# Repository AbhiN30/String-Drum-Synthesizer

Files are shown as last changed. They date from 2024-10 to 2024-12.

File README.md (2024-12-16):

# String/Drum Synthesizer (Initial Project Proposal)

## Team Members:
- Abhi Nayak (arnayak2) 
- Joel Schurgin (joelbs3)

## Problem
A musical artist brings with them a sense of how to evoke certain emotions or create particular atmospheres, but may lack the technical knowledge to bring it to life. Sound design can be challenging as it involves crafting the unique timbres and textures that define a piece of music, which can be both an art and a science. The learning curve is steep, not only because it requires a grasp of complex technical tools but also because it demands a creative intuition that isn't easily taught. Musicians and producers must learn to navigate a vast array of software and hardware tools, each with its own set of knobs, sliders, and buttons. Understanding how to shape sounds means diving deep into the physics of sound waves, the principles of digital signal processing, and the subtleties of different synthesis methods. This process can feel overwhelming, especially for beginners who might feel lost amidst the jargon and the sheer number of options.

## Solution
Our proposal is to build a synthesizer. A synthesizer is a machine that is capable of producing a range of sounds when given a simple key or noise pulse. The range of sounds are controlled by a set of parameters such as filter cutoffs, oscillator types, low frequency oscillators, etc. The proposed solution is two-fold. The first part of the project is to build emotive knobs that feature descriptive ranges such as soft to aggressive or thin to thick. These knobs would also control the internal parameters of the system to achieve the desired effects on the input sound. The other part is to create a system that records a sound and finds the best way to set the synthesizer's internal parameters to recreate it. The intended work flow of this device for a musical artist is to record a sound, tweak the knobs, and play that sound by pressing a key on a MIDI keyboard. It is up to the musician to record the sound into their own recording software for further manipulation.

# Solution Components
## Subsystem 1: Power Block

Purpose/Requirements: This subsystem must be able to power the processor and the USB keyboard. Capacitors will be used to stabilize the power block.

Components:

- 5V DC Power Supply Adapter
- Capacitors
- Subsystem 2: Synthesizer

## Subsystem 2: Software Synthesizer
Purpose/Requirements: This subsystem will generate sounds using the Karplus Strong algorithm which features a pulse generator and an echo chamber (modeled with digital delay, feedback, and filtering). When a note is played on a USB keyboard, this component must be able to change the pitch based on which key is pressed. The algorithm’s parameters must be controllable using potentiometers, but several parameters can be determined as a function of one knob. We chose the Karplus Strong algorithm to reduce the computational load, but we are modifying certain aspects to allow for a greater range of sounds. The pulse that we will use is a blend of noise and sine wave oscillator which are added together and distorted. In addition, there will be some soft distortion applied on the output. In addition, the echo chamber will use 3 IIR filters: highpass, lowpass, and a bell. The choice to use IIR filters is to lower the amount of computation.

We made a demo of the synthesizer algorithm using a digital audio workstation in order to play with parameters and determine the names of the emotive knobs. Below are the emotive knobs and how the corresponding synth parameters should change to implement them:

Aggression

- Synth Params: Pulse distortion, output distortion
- Knob Left: Low distortion
- Knob Right: High distortion

Brightness

- Synth Param: Low pass filter cutoff
- Knob Left: 20 Hz
- Knob Right: 20 kHz

Boominess

- Synth Param: High pass Cutoff
- Knob Left: 20 kHz
- Knob Center: Note pitch
- Knob Right: 20 Hz

Dampening

- Synth Param: Bell Q
- Knob Left: High Q
- Knob Right: Low Q

*Not sure what to call this yet, but it affects how the echo chamber resonates. Note: setting this to around 3.6 kHz sounds good, so it could be fine to keep this completely internal and forgo the corresponding knob.

- Synth Param: Bell frequency
- Knob Left: 20 hz
- Knob Right: 20 kHz

Scratchiness

- Synth Param: Length of pulse
- Knob Left: 0
- Knob Center: 1/(Note pitch)
- Knob Right: 4/(Note pitch)

Sharpness

- Synth Param: Mix between pulse noise and oscillator
- Knob Left: Pulse consists of only oscillator
- Knob Right: Pulse consists of only noise

*Strike weight => Corresponds to simulated weight of object striking the string/drum head.

- Synth Param: Pulse oscillator pitch
- Knob Left: 20 kHz
- Knob Right: 20 hz

Notes:
- The value "note pitch" is determined by USB keyboard input.
- Bell gain is fixed and should be set to attenuate the signal.

Components:

- Microprocessor
- DAC
- Potentiometers for parameters (linear, should be able to snap to center position if center value has meaning other should be smooth all the way through)
- USB Port

## Subsystem 3: Amplifier
Purpose/Requirements: This subsystem should output the smallest possible signal to noise ratio through a guitar cable or headphones. In order to achieve this we will experiment with using several inverting op-amp amplifier circuits in parallel and summing them together with an inverting mixer. The gain of each amplifier will be set, but the volume control will be part of the inverting mixer circuit.

Components:

- Mono 1/4in audio jack
- 4 Op-amps
- Logarithmic Potentiometer (for volume control)

## Subsystem 4: Screen/Monitor
Purpose/Requirements: This subsystem should display the waveform of the sound being processed. The purpose of this subsystem is for the user to be able to receive a visual representation of the sound they are developing using their input pulse and emotive knob manipulations. The screen could enhance the usability of the synthesizer by providing visual indicators or icons for each emotive knob, making it easier for users to identify how different settings affect the overall sound. This would bridge the gap between technical sound parameters and intuitive control.

Components:

- Mono 1/4in audio jack
- Op-amp/Transistors
- Raspberry Pi Screen, 7 inch portable monitor external display
# Criterion For Success
High-Level Goals:

1) Get a simple sound, such as a sine wave at 440 Hz, out of DAC output from the synthesizer subsystem. Should be viewable in an oscilloscope, but not important to hear yet.
2) Add potentiometers to the synthesizer and use to control pitch of simple sound for testing.
3) Build the amplifier in order to hear the previously described sound.
4) Add USB port and code for parsing keyboard input.
5) Use synthesizer algorithms to implement the emotive knobs, starting with the pulse generator and then building the echo chamber.
Reach Goal:

6) Implement the screen into the entire system. It will show the waveform of the generated sound, including its amplitude, frequency, and potential distortions. This helps users better grasp the effect of parameters like distortion, brightness, dampening, etc. This visualization would assist the user in creating more precise and desired sounds.

Important Notes:

-The screen is peripheral and not required for the rest of the system to operate. Therefore implementing it is a reach goal.

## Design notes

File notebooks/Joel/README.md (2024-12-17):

# String-Drum-Synthesizer

Dates:

- Week 1: 10/07/2024-10/11/2024
- Week 2: 10/14/2024-10/18/2024
- Week 3: 10/21/2024-10/25/2024
- Week 4: 10/28/2024-11/01/2024
- Week 5: 11/04/2024-11/08/2024
- Week 6: 11/11/2024-11/15/2024
- Week 7: 11/18/2024-11/22/2024
- Week 8: 11/25/2024-11/29/2024
- Week 9: 12/02/2024-12/06/2024
- Week 10: 12/09/2024-12/13/2024

# Week 1: 10/07/2024-10/11/2024

## This week's objectives and responsibilities:

1. Order Parts (Everyone)
2. Prepare for the Design Review Meeting (Everyone)
3. Develop PCB Schematic (Everyone)

## TA Meeting Notes:

We received feedback on our initial project proposal and Design Document critiquing our visual aid, tolerance analysis, and more ethical/safety concerns.

## Record of what was accomplished:

This week we finalized our Design Document in preparation for the Design Review session. I prepared a demo/mock up of the modified Karplus-Strong algorithm using [Reaper](https://www.reaper.fm/) (commercial software for music making). Our presentation featured explanations of the power block, amplifier subsystem, synthesizer algorithm, and tolerance analysis about transmission lines and audio. We attended another group's presentation on their pinball machine diagnosing tool. I was in charge of the schematic design and was still working out details pertaing to the amplifier and processor preventing us from ordering parts or working on the PCB.

## Partner Summary:

N/A (Worked on everything together this week)

# Week 2: 10/14/2024-10/18/2024

## This week's objectives and responsibilities:

1. Implement modified Karplus-Strong Algorithm in C/C++ (Joel)
2. Research how to display data from STM32 via HDMI (Abhi)

## TA Meeting Notes:

Manvi advised us to add another ethical concern for the Design Document and to clean up the block diagram. In addition, we discussed how to actually acheive a target output impedance. Together with Manvi, we concluded that we needed to conduct more research on the topic.

Below is the final schematic:
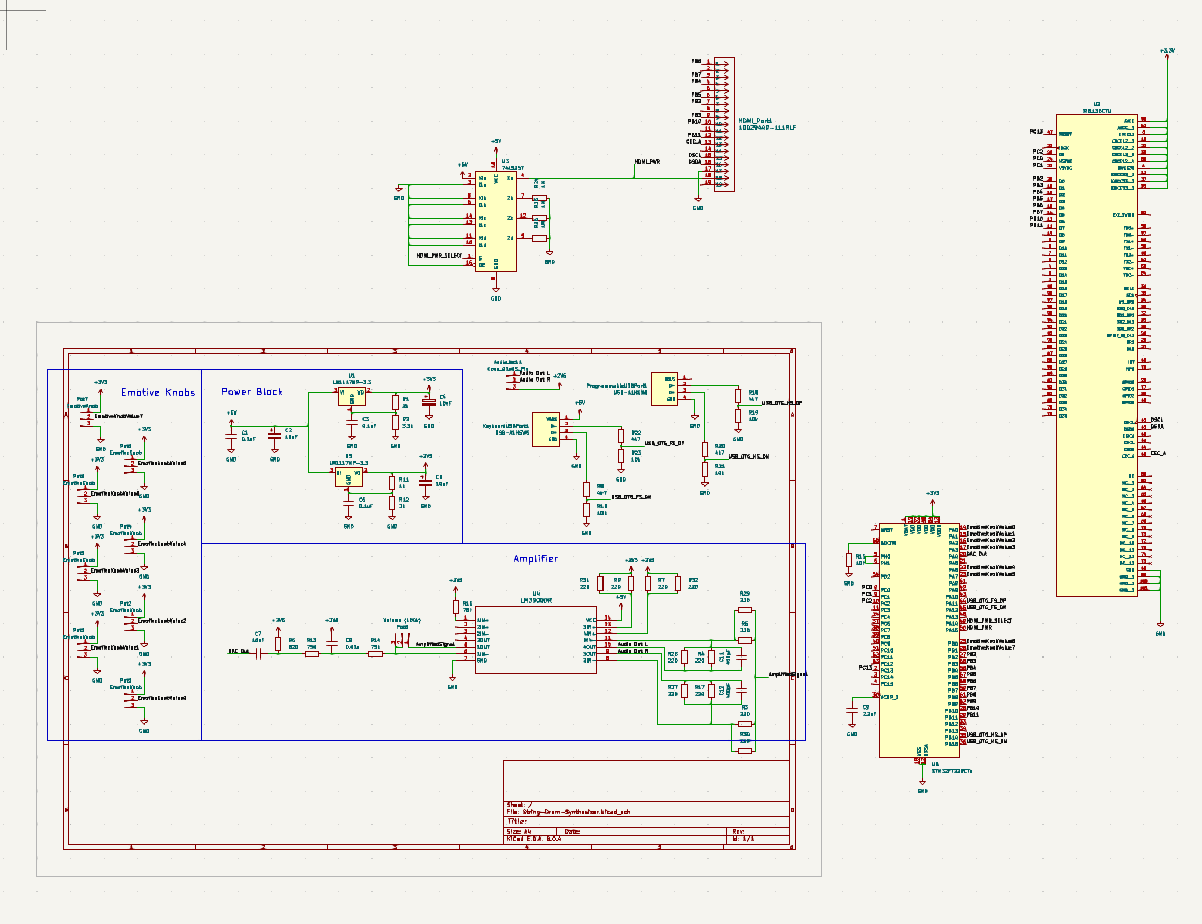
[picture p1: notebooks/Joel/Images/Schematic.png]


## Record of what was accomplished:

This week, we finalized our components list, and Abhi placed the orders. I tried to finish the PCB design but was unable to do so before the PCB review.

## Partner Summary:

- Changed Visual Aid
- Added to schematic for HDMI processing

# Week 3: 10/21/2024-10/25/2024

## This week's objectives and responsibilities:

1. Solder components to PCB (Joel)
2. Configure PCB Enclosure with necessary openings (Abhi)

## TA Meeting Notes:

We discussed our circuit design for each subsystem with Manvi. She said we needed to get our PCB design done.

Below is the final PCB layout:
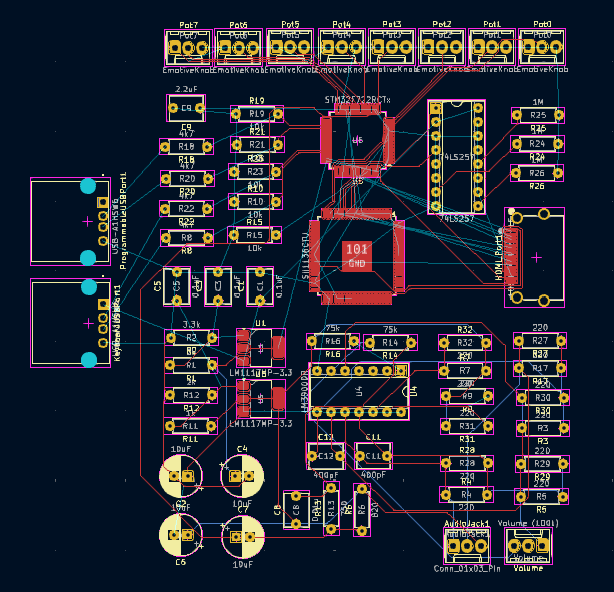
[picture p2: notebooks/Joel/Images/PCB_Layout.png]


## Record of what was accomplished:

I worked on the PCB design and made half of the connections before realizing the HDMI pinout was completely wrong. The datasheet was not used initially for the HDMI connections and upon looking at the schematic it was clear without even looking at the datasheet that the connections were wrong. This caused us to rectify the schematic and PCB over several days and ultimately lead to us missing the 1st round of PCB orders.

## Partner Summary:

- Fixed the circuit schematic for the Screen subsystem with me

# Week 4: 10/28/2024-11/01/2024

## This week's objectives and responsibilities:

1. Individually test Hardware Subsystems to check if R&V is met (Joel)
2. Individually test Software Subsystems to check if R&V is met (Abhi)

## TA Meeting Notes:

We debugged issues with our PCB design with Manvi.

## Record of what was accomplished:

We finalized our PCB but were too late for the 2nd round of orders, so our PCB was in the 3rd round.

## Partner Summary:

- We finished the PCB design

# Week 5: 11/04/2024-11/08/2024

## This week's objectives and responsibilities:

1. Integrate hardware and software subsystems (Everyone)

## TA Meeting Notes:

We received feedback on our Design Document about making the block diagram more compact and readable.

## Record of what was accomplished:

I soldered the amplifier circuit on perf board. There was no signal passed through from the signal generator, so I reassembled on a breadboard. The op-amp I chose created significant crossover distortion, and the solution was to choose a better op-amp.

## Partner Summary:

- Abhi changed the block diagram this week

# Week 6: 11/11/2024-11/15/2024

## This week's objectives and responsibilities:

1. Debugging (Everyone)

## TA Meeting Notes:

I discussed the problems with the amplifier circuit with Manvi.

## Record of what was accomplished:

I soldered components on the PCB only to discover our Power Block schematic had the wrong resistor values. I used voltage regulators, resistors, and capacitors to breadboard and eventually solder a working Power Block onto perf board.

## Partner Summary:

- Abhi wrote "Hello World" on the microprocessor

# Week 7: 11/18/2024-11/22/2024

## This week's objectives and responsibilities:

1. Preparing for and attending the Mock Demo (Everyone)

## TA Meeting Notes:

Our meeting was the Mock Demo this week. We could not show much as some individual parts worked but lacked integration into the rest of the project. We could show that our I2S signal was correct and therefore the double buffer system worked. However, we were not able to show that any knobs were working or able to convert the I2S signal to audio. Manvi advised us to create more structure for our actual demo as well as to focus on our high-level requirement.s

## Record of what was accomplished:

I wrote code for a double buffer system to output audio. In addition I setup to I2S system, which required 3 pins to output (Clock, Write Enable, Data). I verified that Write Enable was oscillating a 48 kHz, our sample rate.

Most of the double buffer code is in 3 functions. 2 are the full and half callbacks. These are called when the STM32 is ready for the next N samples to output. Each of the callbacks changes a pointer to a different half of the buffer to allow for the process to read samples as we write new ones. The last function is to write the samples to this buffer.

Below is the relavent double buffer code:
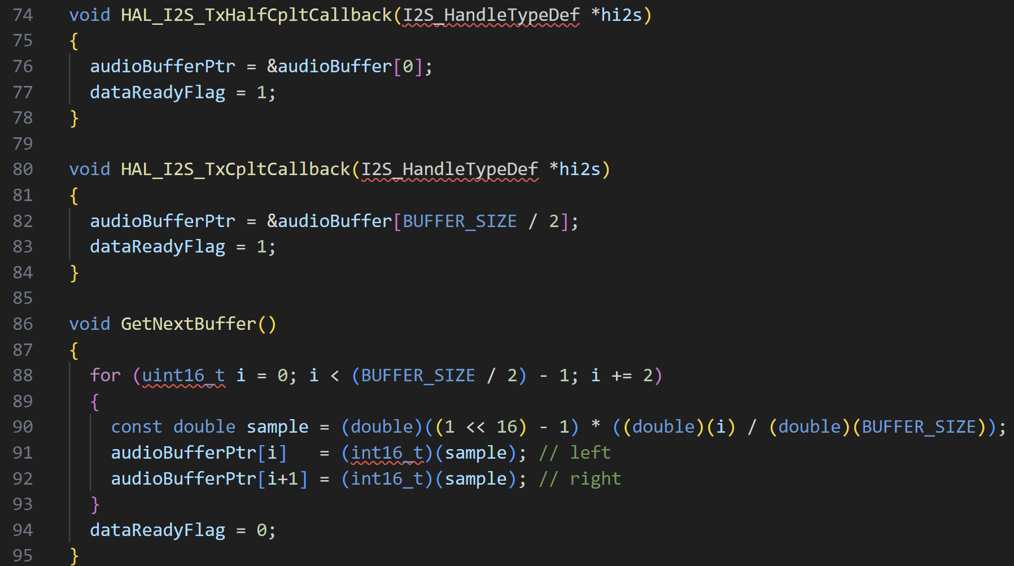
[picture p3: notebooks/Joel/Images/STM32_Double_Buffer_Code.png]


In addition, I tried to use an AD1856N DAC to convert the I2S signal to a PWM wave using the +/-2.5V from the power supply. The IC had no output when viewed with an oscilloscope. One attempt to rectify the problem was to try a larger power supply. In hindsight, I could have tested this with the bench power supply, but instead I spent a day remaking the power block using a 12VDC wall adapter in order to achieve +/-6V. 

## Partner Summary:

- Abhi wrote code to read a value from an emotive knob.

# Week 8: 11/25/2024-11/29/2024

## This week's objectives and responsibilities:

1. N/A, Fall Break (Everyone)

## TA Meeting Notes:

N/A

## Record of what was accomplished:

First, I soldered wires to a USB port and connected to the 5V power on the power supply (that uses a 12VDC wall adapter). When plugging in the MIDI keyboard, the voltage collapsed due to an inability to supply enough current since the keyboard requires 0.5A. I switched to the STM32 NucleoBoard's 5V pin to power which worked for the keyboard.

The USB MIDI standard calls for a device and a host. The keyboard is classified as a device, so our board must function as a host. Specifically, our board must be an "Audio Class" USB host where MIDI is a special case. All that to say I used the MIDI drivers from [this project](https://github.com/Hypnotriod/midi-box-stm32). The debugger managed to start some of the USB host protocol but kept failing to enumerate which involves a sort of handshake between device and host in order find connected devices. The debugger would reach the enumeration stage, fail, then restart the protocol.

Here is the code the debugger was stuck at:
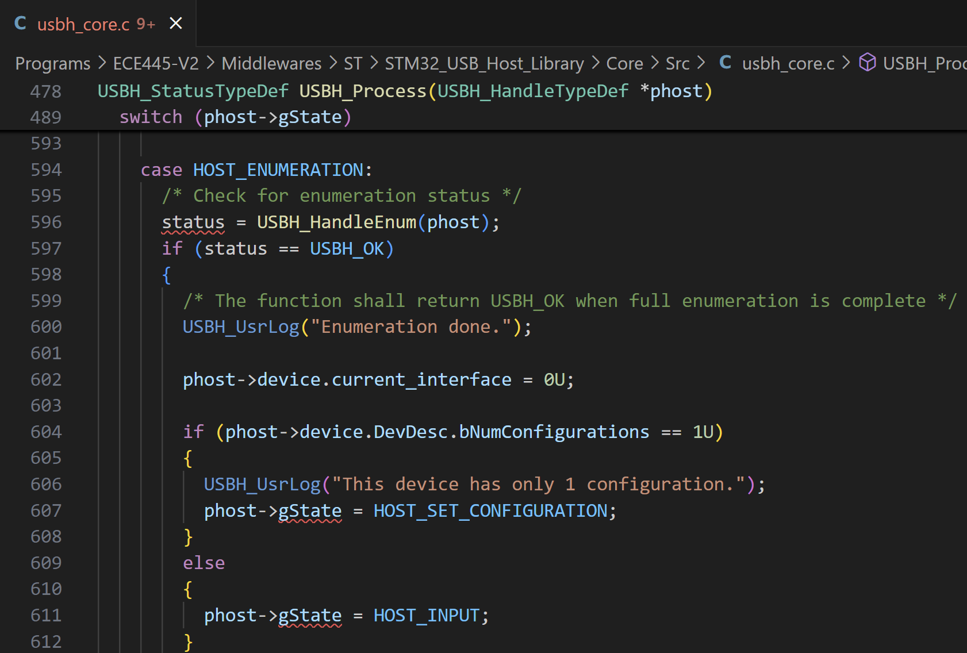
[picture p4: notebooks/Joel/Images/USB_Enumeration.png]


Debugging these protocols took too much time, so I pivoted to a Raspberry Pi which provided an operating system that has USB drivers. In addition, I was able to use [RtMidi](https://www.music.mcgill.ca/~gary/rtmidi/) which provided a single callback function to handle incoming MIDI messages.

Here is the MIDI callback function:


The last issue I tackled this week was getting sound out of the Raspberry Pi. I tried to output PWM waves using the General Purpose Input Output (GPIO) pins. I was unable to view the waveform through an oscilloscope when playing a WAV file from the terminal. However, I was able to hear the file when connecting the HDMI port to a monitor and connecting headphones to the same monitor. That sparked the idea to get a cheap USB adapter in order to move on to more exhilarating problems. To finish getting sound out of the Rasbperry Pi, I programmed a double buffer by loosely following [this tutorial](https://alsamodular.sourceforge.net/alsa_programming_howto.html).

The main processing for the synthesizer will be done in the "processBuffer" function although for now it outputs a sine wave. One thing that confused me was that I am outputing 16-bit audio, but the audio buffer needed to be unsigned chars instead of shorts. However, the reason is because the most signficant byte and least significant bytes are flipped when using the ALSA library.

Here is the Rasbperry Pi double buffer code:
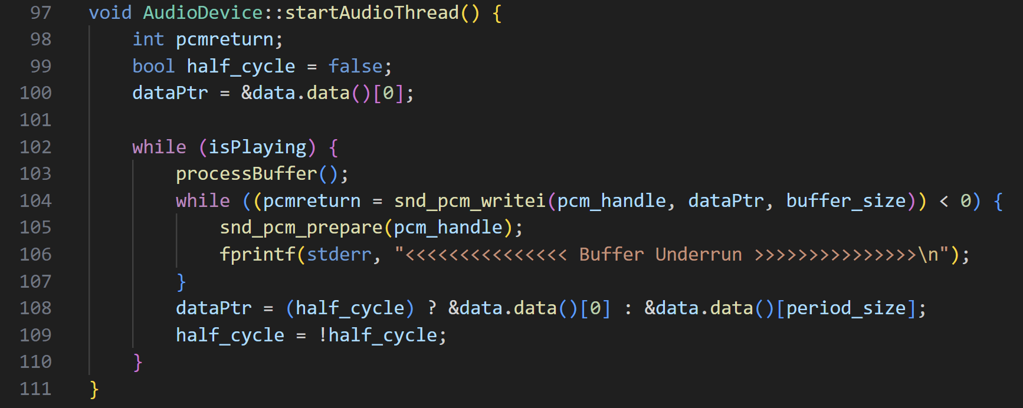
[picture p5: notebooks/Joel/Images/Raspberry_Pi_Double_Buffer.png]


## Partner Summary:

- Took a break

# Weeks 9 & 10: 12/02/2024-12/13/2024

## This week's objectives and responsibilities:

1. Final Demo/Presentation (Everyone)

TA Meeting Notes:

N/A

## Record of what was accomplished:

This week, Abhi and I built the enclosure by sanding a metal tea box and drilling holes for knobs, a switch, and USB/HDMI ports for the Raspberry Pi. We printed labels for the knobs and ports.

Here is our physical design:
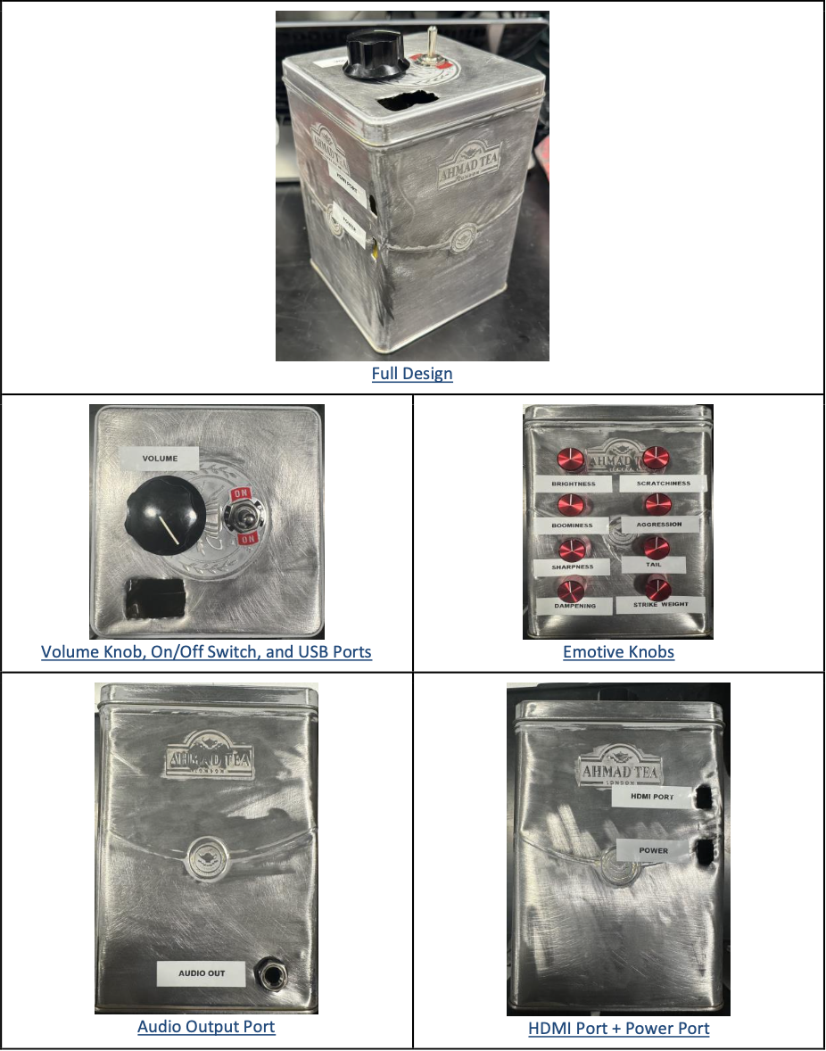
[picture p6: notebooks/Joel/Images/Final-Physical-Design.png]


Next, I tried using the ADC0808 chip which is an 8-bit ADC and 8 channel multiplexer to convert the voltages of the knobs into 8-bit parallel signals. This did not work and I wasn't sure why. Being days before our demo, I suggested we interface with the STM32 as we had already successfully used it's ADC inputs to read values from the Emotive knobs.

To transfer knob data, we wrote a program on the STM32 that continuously outputs 8-bits (via GPIO pins) from a single knob. The Raspberry Pi sends 3 select bits to the STM32 to choose which knob value to read. The Raspberry Pi cycles through each knob continuously updating its value and storing it in an array in a separate thread from the audio processing. Emotive knobs update on the order of milliseconds while the audio buffer is processed in 5.333 milliseconds (256 samples / 48 kHz sample rate). This means we are at best getting a 1-2 knob values per audio buffer. However, this is okay since 

Here is the STM32 emotive knob callback function:
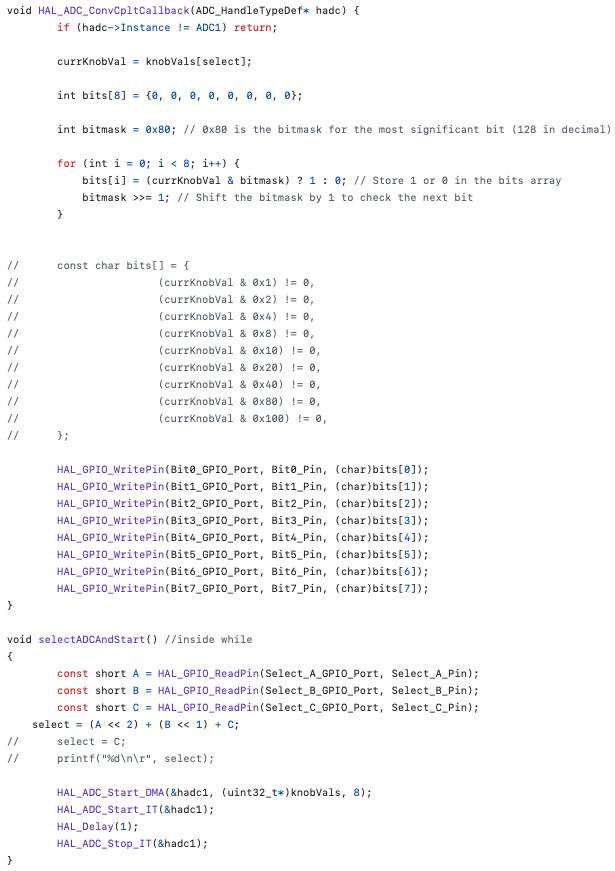
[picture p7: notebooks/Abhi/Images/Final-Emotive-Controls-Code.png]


Here is the Raspberry pi emotive knob readValue function:
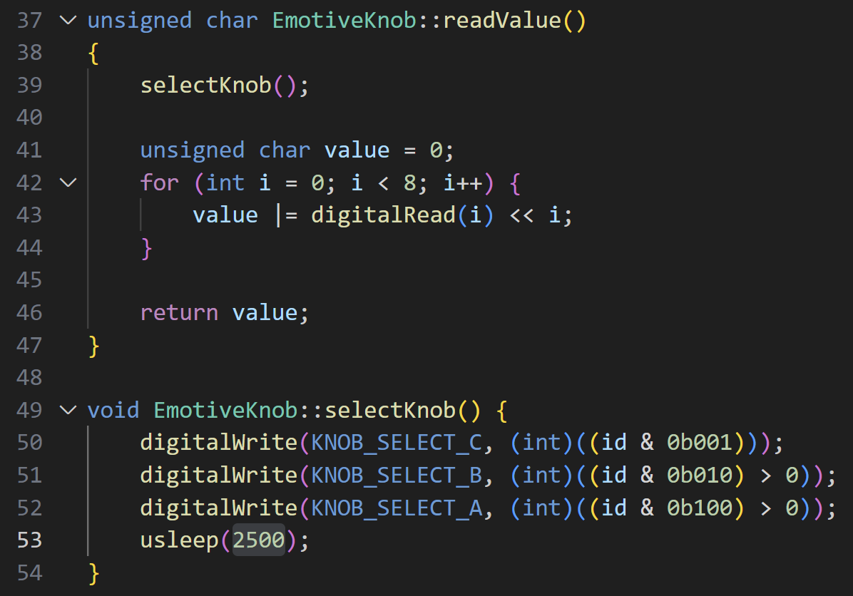
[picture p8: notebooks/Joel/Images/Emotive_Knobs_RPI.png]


I implemented the Modified Karplus-Strong algorithm this week too. The first step was to generate white noise. I first tried std::normal_distribution, but the noise didn't sound as spectrally white. I did not have time to properly test this with a spectrogram, so I just tried to verify that it sounded like the Ocean. std::uniform_distribution worked better for this purpose. Then, I turned this into a short pulse which had a length that was a function of Scratchiness and also inversely proportional to pitch.

The second step was to repeat the noise pulse using a circular buffer. In order to properly repeat the pulse, I had to call "circular_buffer.popSample", do some processing, then call "circular_buffer.pushSample."

Here is the CircularBuffer class definition:
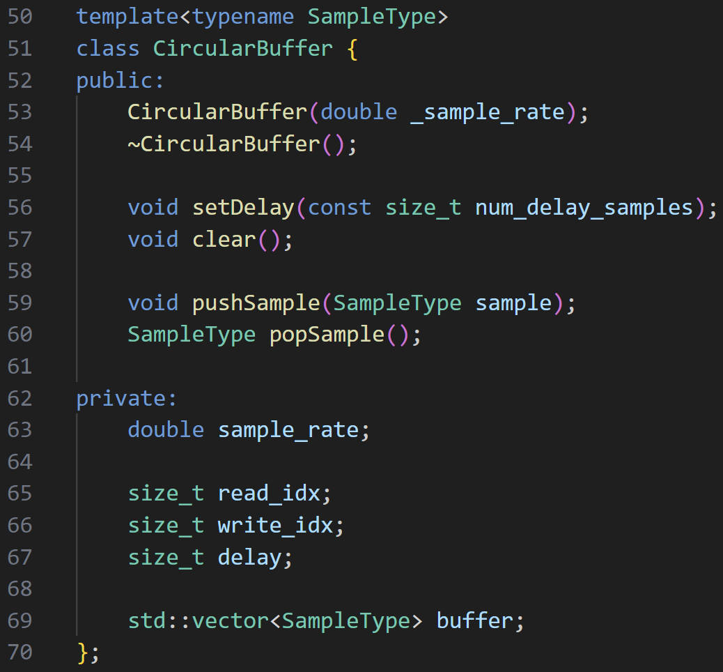
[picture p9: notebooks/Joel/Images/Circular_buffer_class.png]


The next step to develop the synthesizer was to create a biquad filter. I chose a biquad filter since I needed a highpass, lowpass, and peak filter. The same architecture can be used for all three by simply changing the coefficients. To test the filters, I filtered continuous white noise from earlier and set various cutoff frequencies. Again I had to verify by ear using simple sanity checks due to lack of time. At a cutoff of 20 Hz, the highpass let all the sound through and the lowpass was silent. The opposite was true of 20 kHz. The peak filter was harder to verify, but acted like a mild highpass when set to a low frequency such as 100 Hz with a low Q (~0.1-0.5) and negative gain (dB). Of course not all low frequecies were blocked but they shouldn't have been. The opposite was also true when set to a high frequency such as 10 kHZ. 

I then incorporated the filters into the algorithm. Once the dampening parameter was added, I was able to verify that the Q parameter from the peak filter worked as well since a low Q meant high dampening and a high Q meant low dampening (following how the mock up from Week 1 sounded when changing this parameter). The peak filter is set to 3.6 kHz and -6.0dB gain in the final algorithm since these values sounded good to me.

Here is the Filter class definition:
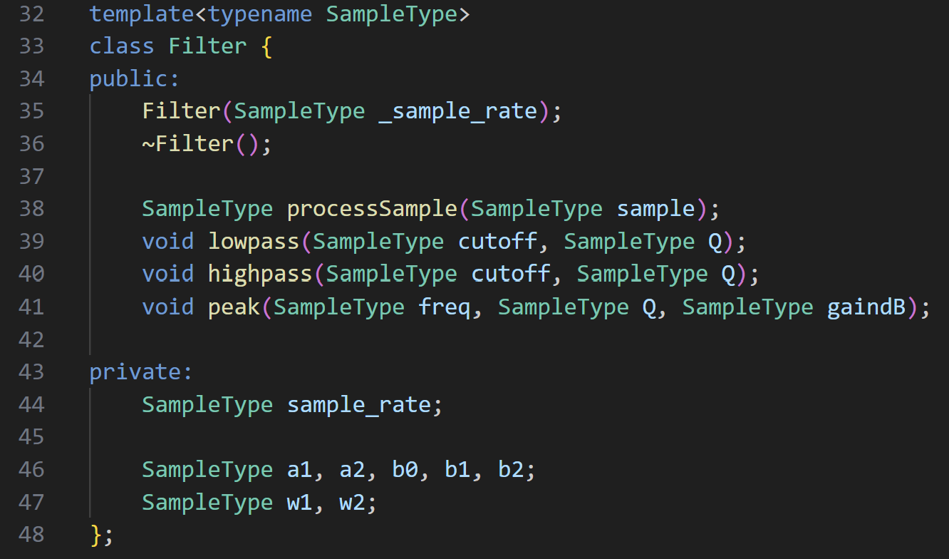
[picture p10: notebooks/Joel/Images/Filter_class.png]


I created a simple sine oscillator using std::sin. I tried to write code for a fast sine approximation, but it didn't work in time for the demo. I changed the pitch of the oscillator and outputted a steady tone. Low frequencies sounded lower than high frequencies, which was all I was able to verify. Lastly, I added the oscillator to the noise pulse in the full algorithm.

Partner Summary:

- Worked on Emotive Knob subsystem with me
- Updated Design Document

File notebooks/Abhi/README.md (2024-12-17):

# Abhi's Weekly Worklog

Dates:
- Week 1: 10/07/2024-10/11/2024
- Week 2: 10/14/2024-10/18/2024
- Week 3: 10/21/2024-10/25/2024
- Week 4: 10/28/2024-11/01/2024
- Week 5: 11/04/2024-11/08/2024
- Week 6: 11/11/2024-11/15/2024
- Week 7: 11/18/2024-11/22/2024
- Week 8: 11/25/2024-11/29/2024
- Week 9: 12/02/2024-12/06/2024
- Week 10: 12/09/2024-12/13/2024

# Week 1: 10/07/2024-10/11/2024

The objectives and responsibilities for the week were initially set in the Design Document as follows...

1. Order Parts (Everyone)
2. Prepare for the Design Review Meeting (Everyone)
3. Develop PCB Schematic (Everyone)

TA Meeting Notes:

During the TA meeting for this week, Manvi gave us some feedback on our initial Project Proposal document
and let us know that we needed to fix up our visual aid, add more details to the tolerance analysis,
and add additional ethical and safety concerns for the Design Document.

Record of what was accomplished:

In terms of our accomplishments for the week, we were able to meet to finalize our Design Document and prepare
for the Design Review session. Overall, I thought it went pretty well as we were able to effectively communicate
the different components of our block diagram and thoroughly explain our tolerance analysis for the Amplifier subsystem. In addition to this,
we had the opportunity to attend another group's design review presentation and we filled out the Peer Design Review Google Form.
Unfortunately, we were unable to place the order for our parts this week, however we got much closer to finalizing our entire parts list.
Since we were still deciding on parts, we didn't move on to developing the PCB schematic either.

Partner Summary:

N/A (Worked on everything together this week)

# Week 2: 10/14/2024-10/18/2024

The objectives and responsibilities for the week were initially set in the Design Document as follows...

1. Implement modified Karplus-Strong Algorithm in C/C++ (Joel)
2. Research how to display data from STM32 via HDMI (Abhi)

TA Meeting Notes:

During the TA meeting for this week, Manvi mainly gave us some feedback on our Design Document and let us know that we needed to fix up our 
block diagram to make it less colorful and include voltages and arrow labels, and add one more ethical concern for the Design Document. 
From her feedback from the previous week, I redrew our visual aid with more specifically labeled components and dimensions as shown below.

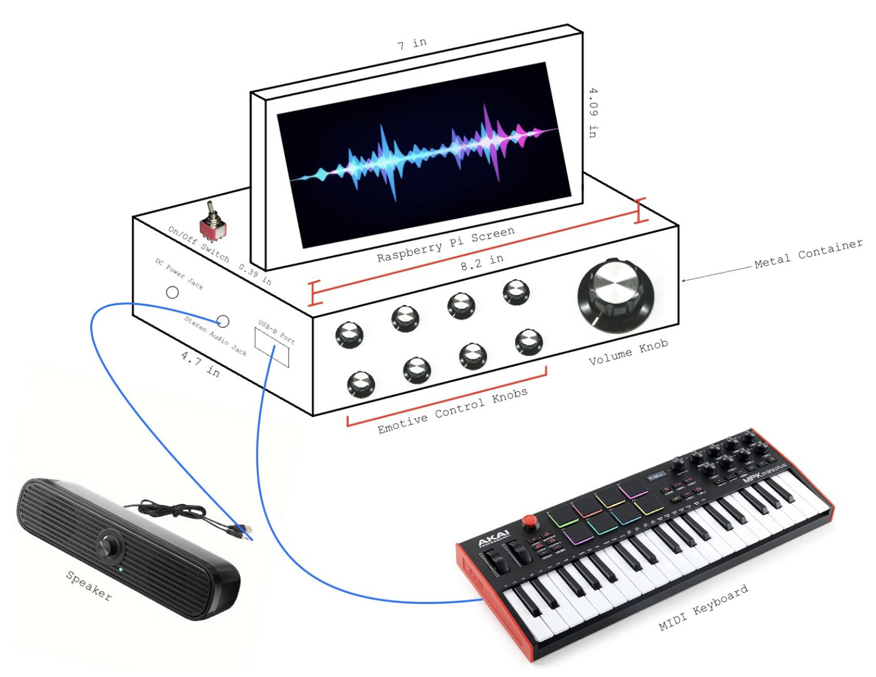
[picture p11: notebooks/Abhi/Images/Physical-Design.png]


Record of what was accomplished:

In terms of our accomplishments for the week, we were able to finalize our components list and I placed the orders for our group as shown in the image below. We also both
worked on the Teamwork Evaluation Form to provide some early feedback on our team dynamic.

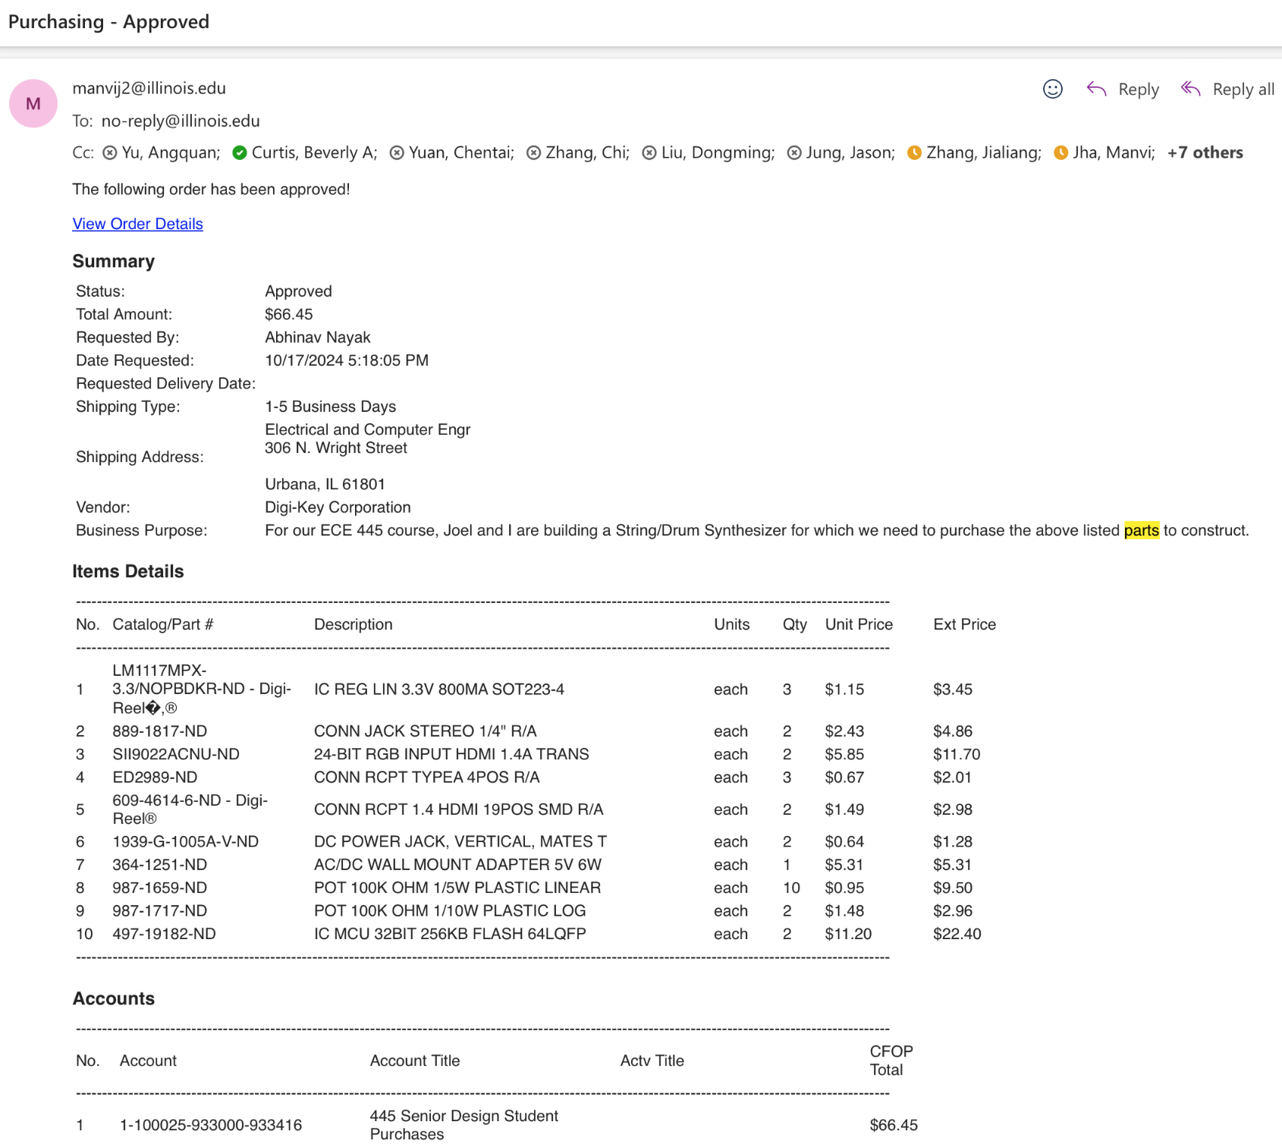
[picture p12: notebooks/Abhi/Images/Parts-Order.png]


Partner Summary:

- Added additional detail to the tolerance analysis from a hardware perspective
- Started building the subsystem schematics on KiCAD

# Week 3: 10/21/2024-10/25/2024

The objectives and responsibilities for the week were initially set in the Design Document as follows...

1. Solder components to PCB (Joel)
2. Configure PCB Enclosure with necessary openings (Abhi)

TA Meeting Notes:

During the TA meeting for this week, Manvi gave us some feedback on our subsystem circuit design, mostly telling us that it looked good and we needed to start prioritizing
getting our PCB design done. From her feedback from the previous week, I redrew our block diagram to be less colorful and be more thoroughly labeled.

Initial Block Diagram:

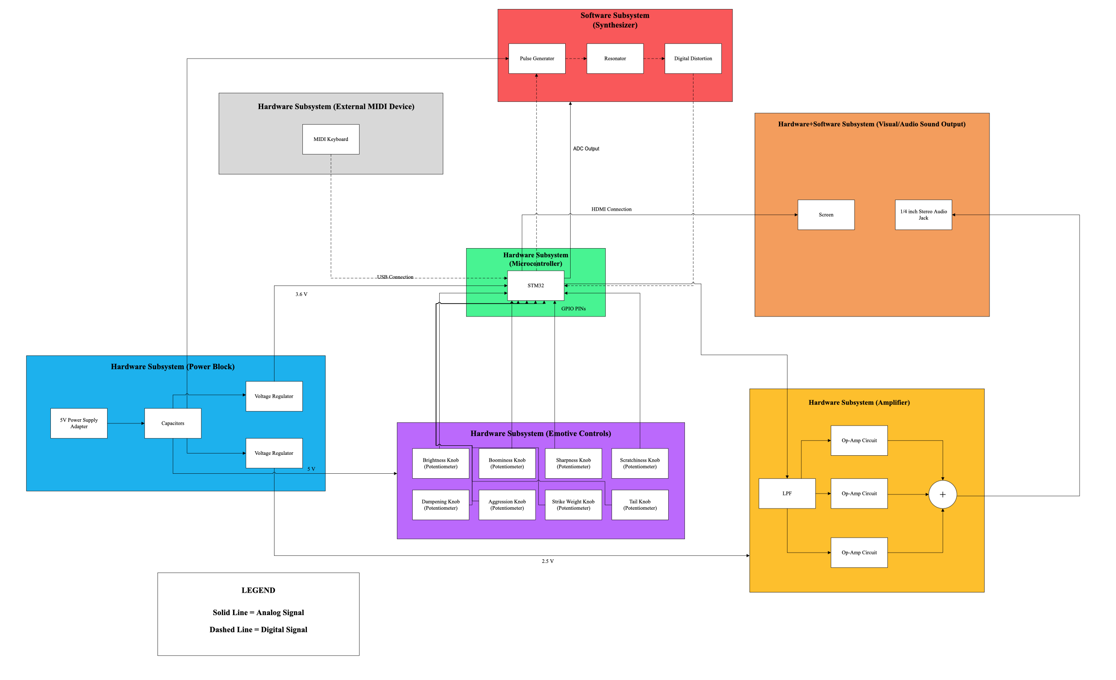
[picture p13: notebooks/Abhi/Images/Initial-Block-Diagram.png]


Updated Block Diagram:

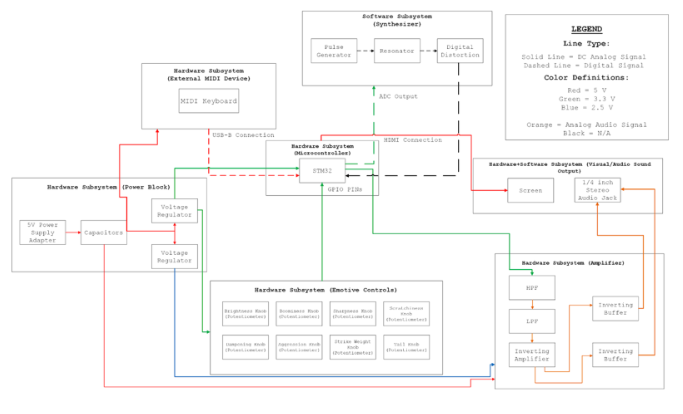
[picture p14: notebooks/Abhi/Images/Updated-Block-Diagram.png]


Record of what was accomplished:

In terms of our accomplishments for the week, I fixed the errors in our circuit schematic, specifically in the Screen subsystem. I had initially read the datasheet incorrectly,
so I needed to reconfigure some of the pins, such as the HSYNC, VSYNC, HPD, as well as some of the TMDS signal inputs to the HDMI port.

Shown below is our updated Screen Subsystem Schematic:

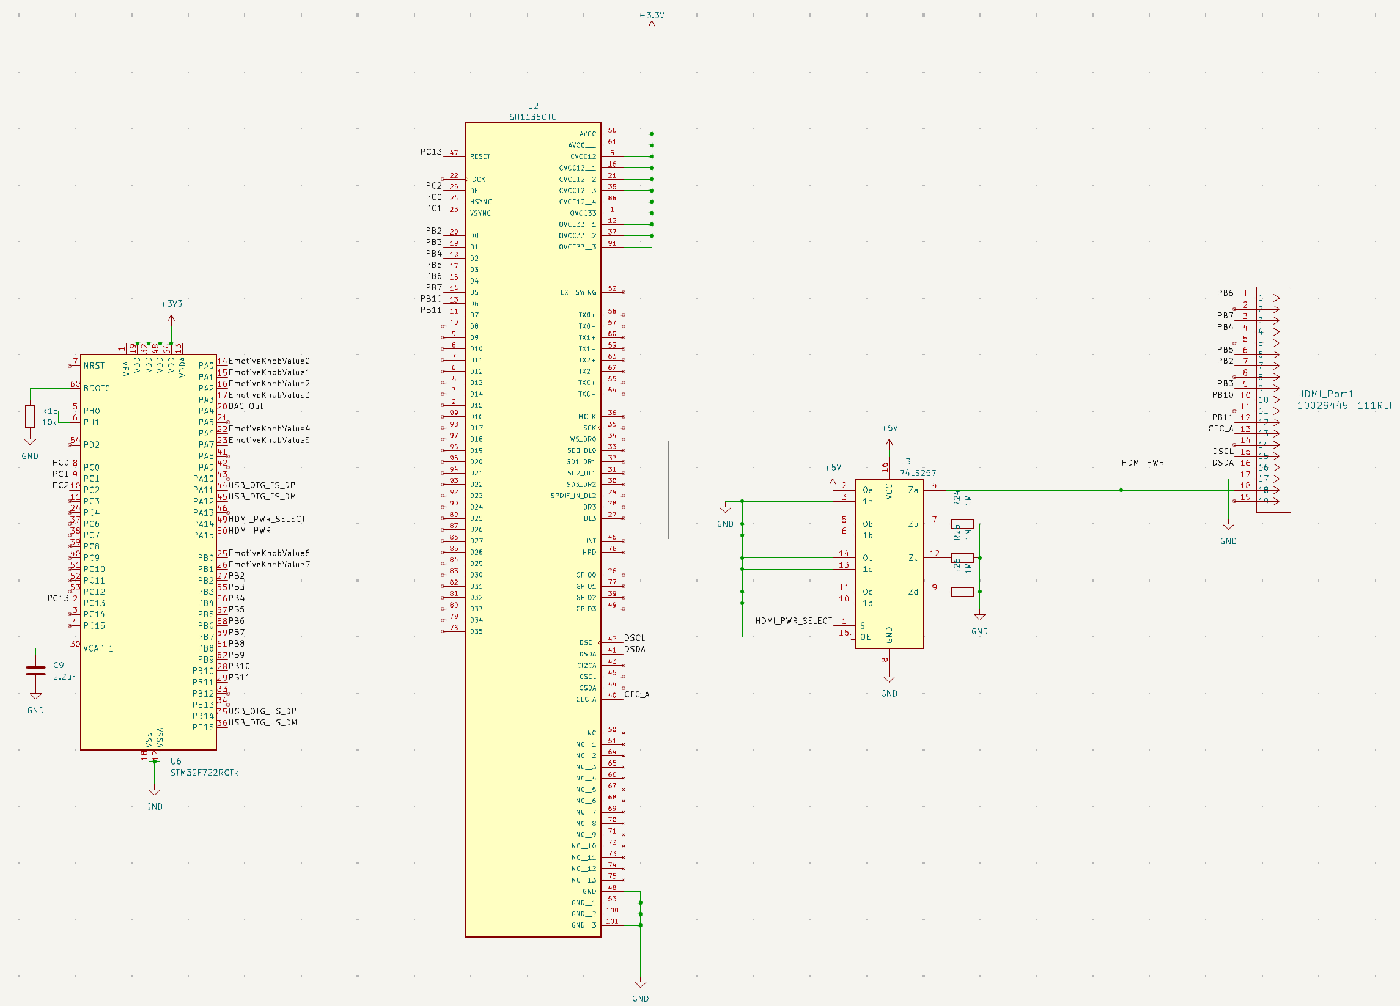
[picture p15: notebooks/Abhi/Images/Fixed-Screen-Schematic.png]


Partner Summary:

- After I fixed the circuit schematic for the Screen subsystem, Joel started fixing the traces for it within the actual PCB design.

# Week 4: 10/28/2024-11/01/2024

The objectives and responsibilities for the week were initially set in the Design Document as follows...

1. Individually test Hardware Subsystems to check if R&V is met (Joel)
2. Individually test Software Subsystems to check if R&V is met (Abhi)

TA Meeting Notes:

During the TA meeting for this week, Manvi mostly just helped us debug some of the issues with our PCB design.

Record of what was accomplished:

In terms of our accomplishments for the week, Joel and I finalized our PCB design.

Shown below is our finalized PCB design:

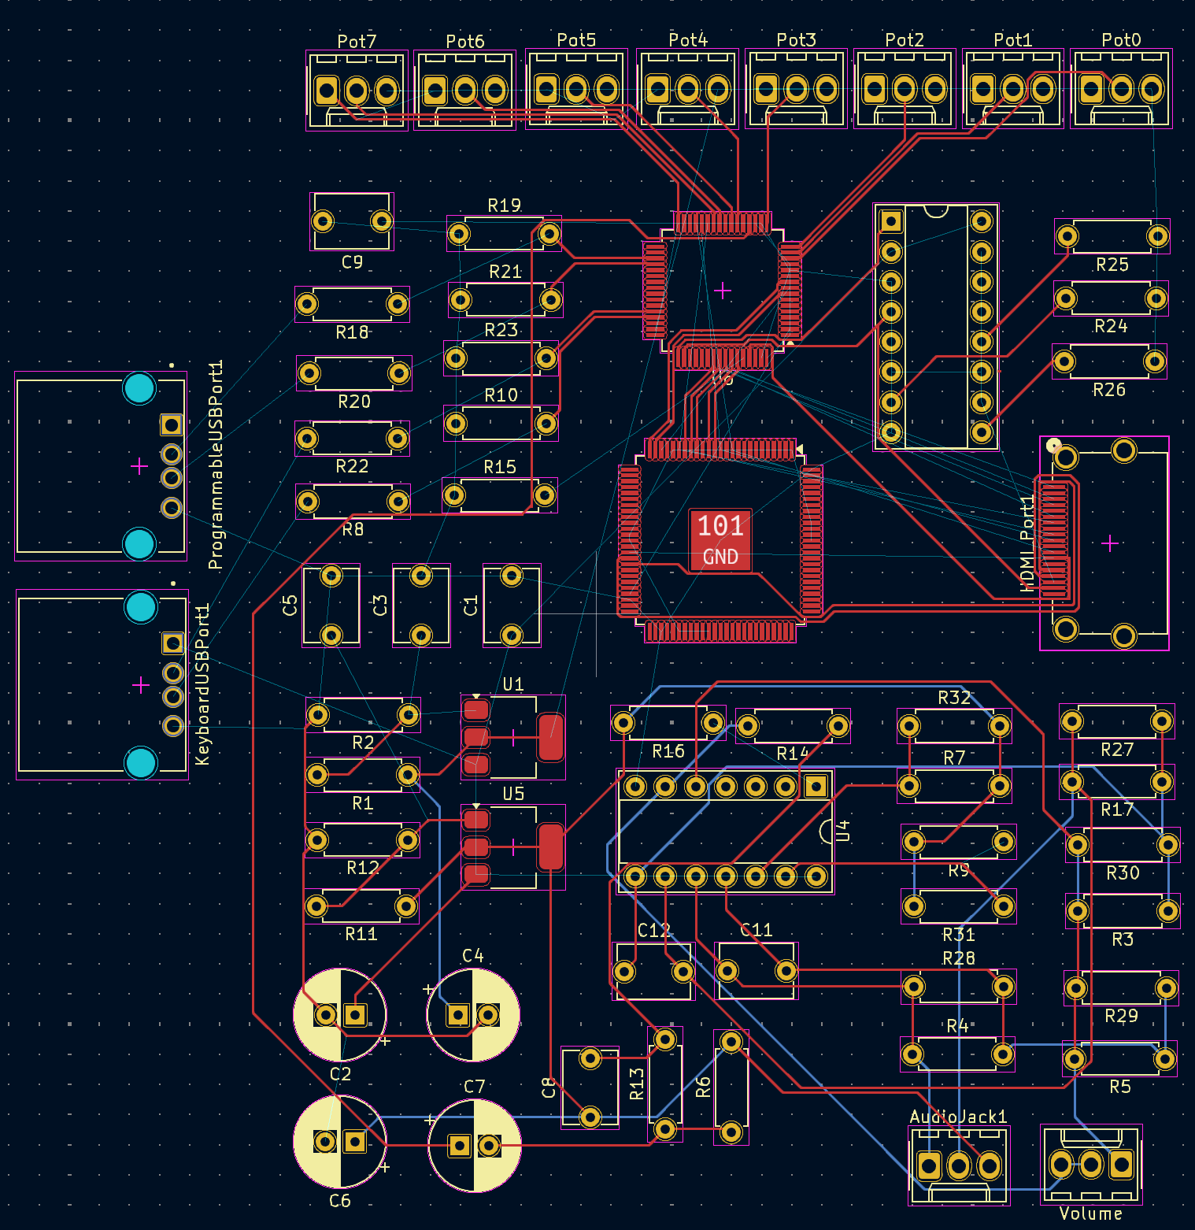
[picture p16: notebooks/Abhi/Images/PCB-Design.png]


Partner Summary:

- After we finished up our PCB design, Joel sent the files over to Manvi to place our PCB order.

# Week 5: 11/04/2024-11/08/2024

The objectives and responsibilities for the week were initially set in the Design Document as follows...

1. Integrate hardware and software subsystems (Everyone)

TA Meeting Notes:

During the TA meeting for this week, Manvi gave us some feedback on our Design Document, mainly saying that we needed to fix
our block diagram by making it more compact and increasing the font-size within the blocks.

Record of what was accomplished:

In terms of my accomplishments for the week, I fixed the block diagram according to Manvi's comments and also, completed my individual progress
report that highlighted my progress with the Screen subsystem at the circuit level and my plans for the software integration in the coming weeks.

Shown below is our finalized PCB design:

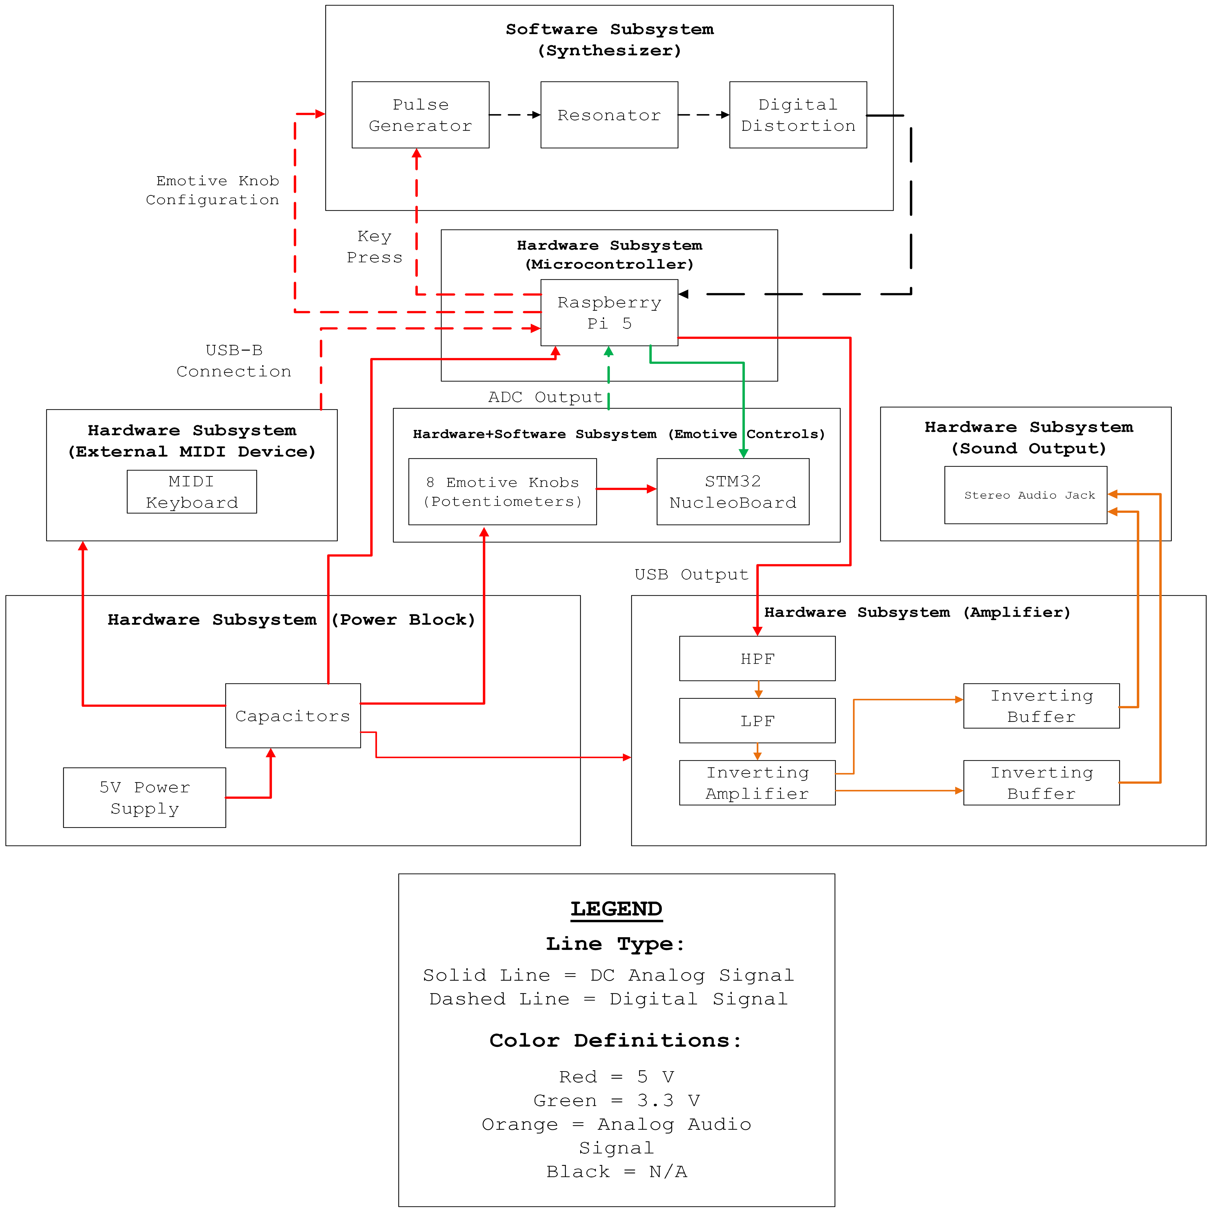
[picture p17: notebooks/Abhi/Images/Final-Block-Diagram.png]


Partner Summary:

- During this week, Joel worked on building a physical circuit for the Amplifier subsystem to verify that the circuit that was drawn in KiCAD was
functional in practice.

# Week 6: 11/11/2024-11/15/2024

The objectives and responsibilities for the week were initially set in the Design Document as follows...

1. Debugging (Everyone)

TA Meeting Notes:

During the TA meeting for this week, I went over some of my progress with Manvi. I showed her some of the test scripts I had written for the Microprocessor and
explained to her that I'm still reading through the relevant STM32 documentation about programming the Microprocessor and flashing firmware to it.

Record of what was accomplished:

In terms of my accomplishments for the week, I started writing a script to write "Hello World!" on the Microprocessor using C to prove that the Microprocessor could perform
computations. However, after writing some skeleton code, I decided to instead prove that it was working from a visual perspective and so, I instead wrote code to write to a GPIO pin on the processor, which
I would connect directly to an LED and if the LED lit up after the program ran, this would verify that the Microcontroller was functioning as expected.

Shown below is a snippet of my "Hello World!" test program:

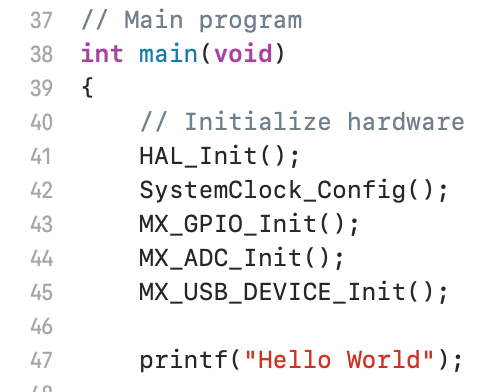
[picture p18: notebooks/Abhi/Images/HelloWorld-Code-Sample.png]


Another accomplishment for the week was that we were able to begin testing the Microcontroller and Emotive Controls subsystems on the PCB. After soldering the Power Block subsystem and connecting it to power, the potentiometers
in the Emotive Controls subsystem were providing accurate voltage readings from the multimeter, however we realized that the Microprocessor was not receiving any power. To debug this, we went back to the PCB design on KiCAD and 
found that some of the 3.3 V trace lines weren't properly connected to the Vdd pins. To fix this issue, we attempted to connect some jumper wires to these pins, but this ended up causing our Microprocessor to overheat significantly,
so we decided to switch to using an STM32 NucleoBoard instead.

Partner Summary:

- During this week, Joel soldered all of the components from the various subsystems onto the PCB and tested the Power Block and Amplifier subsystems on the PCB to verify its functionality.

# Week 7: 11/18/2024-11/22/2024

The objectives and responsibilities for the week were initially set in the Design Document as follows...

1. Preparing for and attending the Mock Demo (Everyone)

TA Meeting Notes:

This was one of our more important TA meetings as it was the one where we performed our Mock Demo. Unfortunately, we ran into many errors in our design and thus, we weren't able to show a fully functional product
by this point. However, we were able to show that the system could make sound and also, that the Emotive knob values could update in real-time. Also, since we were working so intensely on trying to get the Synthesizer to work, we didn't prepare much for the demo itself and so, our presentation of our project was very scattered and unorganized. Manvi's feedback for us this week was that we needed to practice a structure for how we would demonstrate our project during the final demo and also, that we needed to fix the functionality of our subsystems to have a presentable final product.

Record of what was accomplished:

In terms of my accomplishments for the week, I finished writing the script to blink an LED on and off using C to prove that our new STM32 NucleoBoard was working properly. Once I did this, we tested the code and it worked as expected, proving
that the STM32 NucleoBoard was a viable option to provide some of our system processing. I also finished up reading the STM32 documentation and figured out to configure the pins on the microcontroller to perform their required functions, write code for the processor to use,
debug the code using GDB, and lastly, generate the binary file to be uploaded to the processor to constantly perform the computations that we need. I learned that the previously listed steps would need to be completed via the STM32CubeIDE software and in order to upload the binary file, we would need to use the STM32CubeProgrammer Software. Other than this, we were able to write some code to prove that the Emotive knob values could be digitized and updated as they were being changed.

Shown below is a snippet of the preliminary code we wrote to read the Emotive knob values as they were updated:

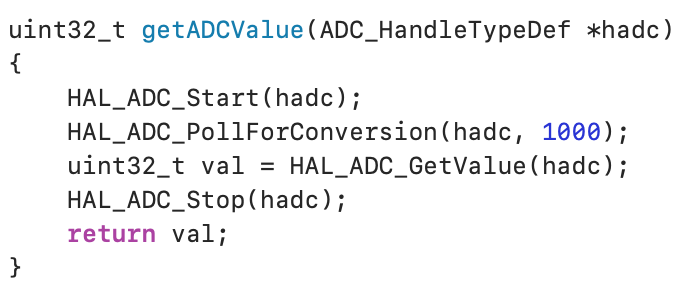
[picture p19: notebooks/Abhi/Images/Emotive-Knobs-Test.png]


Partner Summary:

- During this week, Joel finished building the Power Block and Amplifier subsystems. He also wrote some code to create a double buffer system for Audio output with the I2S protocol on the STM32 NucleoBoard.

# Week 8: 11/25/2024-11/29/2024

The objectives and responsibilities for the week were initially set in the Design Document as follows...

1. N/A, Fall Break (Everyone)

TA Meeting Notes:

N/A

Record of what was accomplished:

N/A (Fall Break)

Partner Summary:

- During Fall Break, Joel took some time to work on the Synthesizer algorithm in C++ and also, write some code to read the values from the Emotive Knobs on the Raspberry Pi.

# Weeks 9 & 10: 12/02/2024-12/13/2024

The objectives and responsibilities for the week were initially set in the Design Document as follows...

1. Final Demo/Presentation (Everyone)

TA Meeting Notes:

N/A

Record of what was accomplished:

In terms of our accomplishments for the week, we were able to finally build an enclosure for our Synthesizer. We did this by first heading to the FabLab on campus to be our primary workstation to complete this step. 
In the FabLab, we spent a few hours sanding down a Metal Container, drilling holes into the container for our ports and Emotive knobs, sanding down these newly made holes to ensure the enclosure would be safe to hold, and lastly,
printing out labels for each of the Emotive knobs and ports for the user to have easy accessibility to our design.

Shown below is our final physical design:



In addition to this, we worked on writing a script to convert the analog Emotive Knob values to be digital inputs to the Raspberry Pi. 

The program worked as follows (single-knob perspective) (explained in more detail in the final report):

1. Turn an emotive knob in a particular direction to toggle the voltage between 0 and 3.3 Volts.
2. Simultaneously, three select bits will be sent from the Raspberry Pi to determine which knob to read (in this case, the knob that was turned).
3. Next, it will convert the analog value of the knob into a digital one using the STM32 NucleoBoard's built-in ADC.
4. After doing this, it will take the converted value and translate it into 8 separate bits to be sent in parallel back to the Raspberry Pi to be processed within the Synthesizer Algorithm.
5. Steps 2-4 will be constantly repeated in order to provide real-time updates of the knob values.

Shown below is our final Emotive knobs code on the STM32 NucleoBoard:



Moving on, I also finalized our design document with all of the changes we had made to our system. For example, the first week I was trying to implement the Screen subsystem by first trying to visualize an arbitrary sine wave on the Raspberry Pi, however, after many attempts, I kept
getting horizontal lines that panned across the entire window that would flash quickly up and down the screen. Because we were getting so close to the final demo day, I decided it was best to move on to fixing different parts of our project instead,
such as the Emotive Controls as listed before, and thus, removed our Screen subsystem from our final Design Document.

Another highlight of the first week was that we completed our final demonstration and although we weren't able to fully complete our project, we were still able to demonstrate a semi-functional product as a whole with most subsystems working as intended. In this week, we also
attended and filled out the form for one of our peer's final demonstration that was focused on Soil Moisture readings, which was something I found very interesting as I conducted research in this field last year. Lastly, in this week, we finalized our final presentation slide deck.

Here's a link to our Extra Credit Demo Video to show our project's capabilities by this final week:
https://www.youtube.com/embed/Ir_v7jes1CY?si=TUmOt4E8HuO2rle-

In Week 10, we completed our Final Presentation and attended one of our peer's final presentation and filled out the google form for it. I thought it was really cool to learn about how they designed and made calculations for their battery recharging system. In addition to this,
we also completed our final report and completed our Lab Checkout with Manvi.

Partner Summary:

- In the first week, Joel specifically focused on finishing the Synthesizer Subsystem on the Raspberry Pi.

# Conclusions

Although we didn't follow much of our initial weekly schedule that we created in the early stages of the Design Document, by the end of this semester, we still were able to find many successes with our project. Starting with the Power Block subsystem, we were able to produce a stable 5 Volts and 3.3 Volts for the entire system as we initially intended. Next, in the External MIDI Device subsystem, we were able to retrieve data from the keyboard upon keypress, such as the pitch of the key, with very low latency. Moving on to the Emotive Controls subsystem, we were able to both convert the analog values of the knobs into digital ones and also, send these values to the main processor within the Raspberry Pi as they were being updated in real-time. In terms of the final functionality, we were able to get our modified Karplus-Strong Algorithm working in practice as we could hear sound after each keypress and also tune the sound to our liking using the physical Emotive knobs.

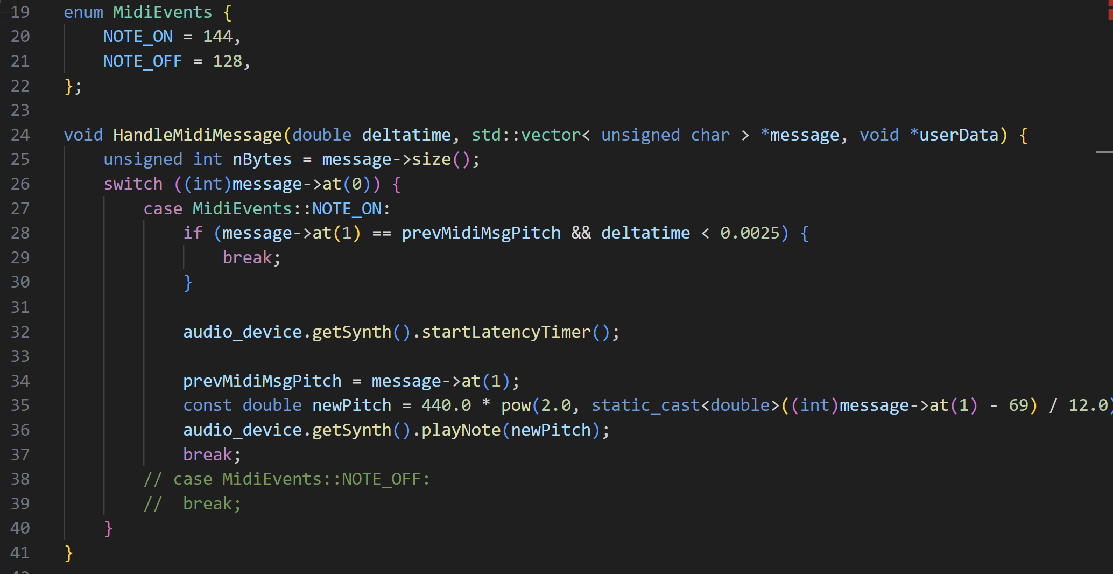
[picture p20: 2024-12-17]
notebooks/Joel/Images/MIDI_Callback.png

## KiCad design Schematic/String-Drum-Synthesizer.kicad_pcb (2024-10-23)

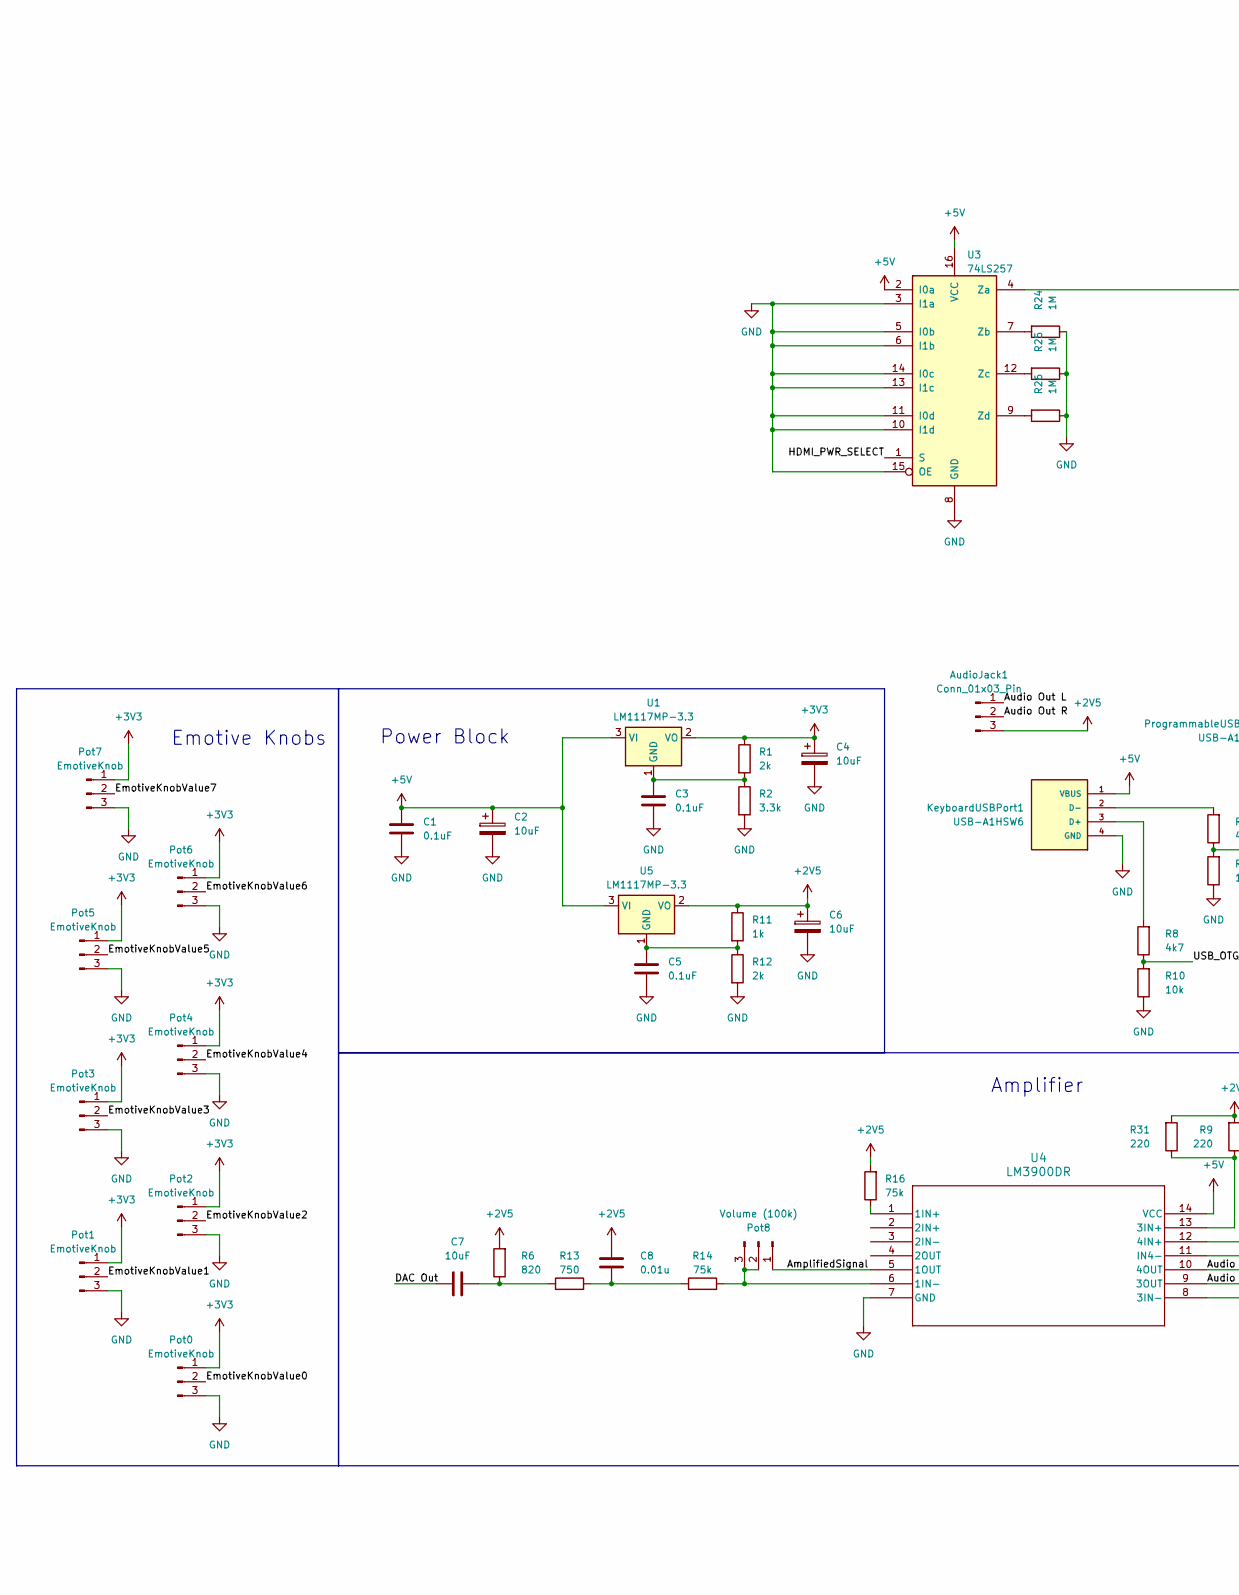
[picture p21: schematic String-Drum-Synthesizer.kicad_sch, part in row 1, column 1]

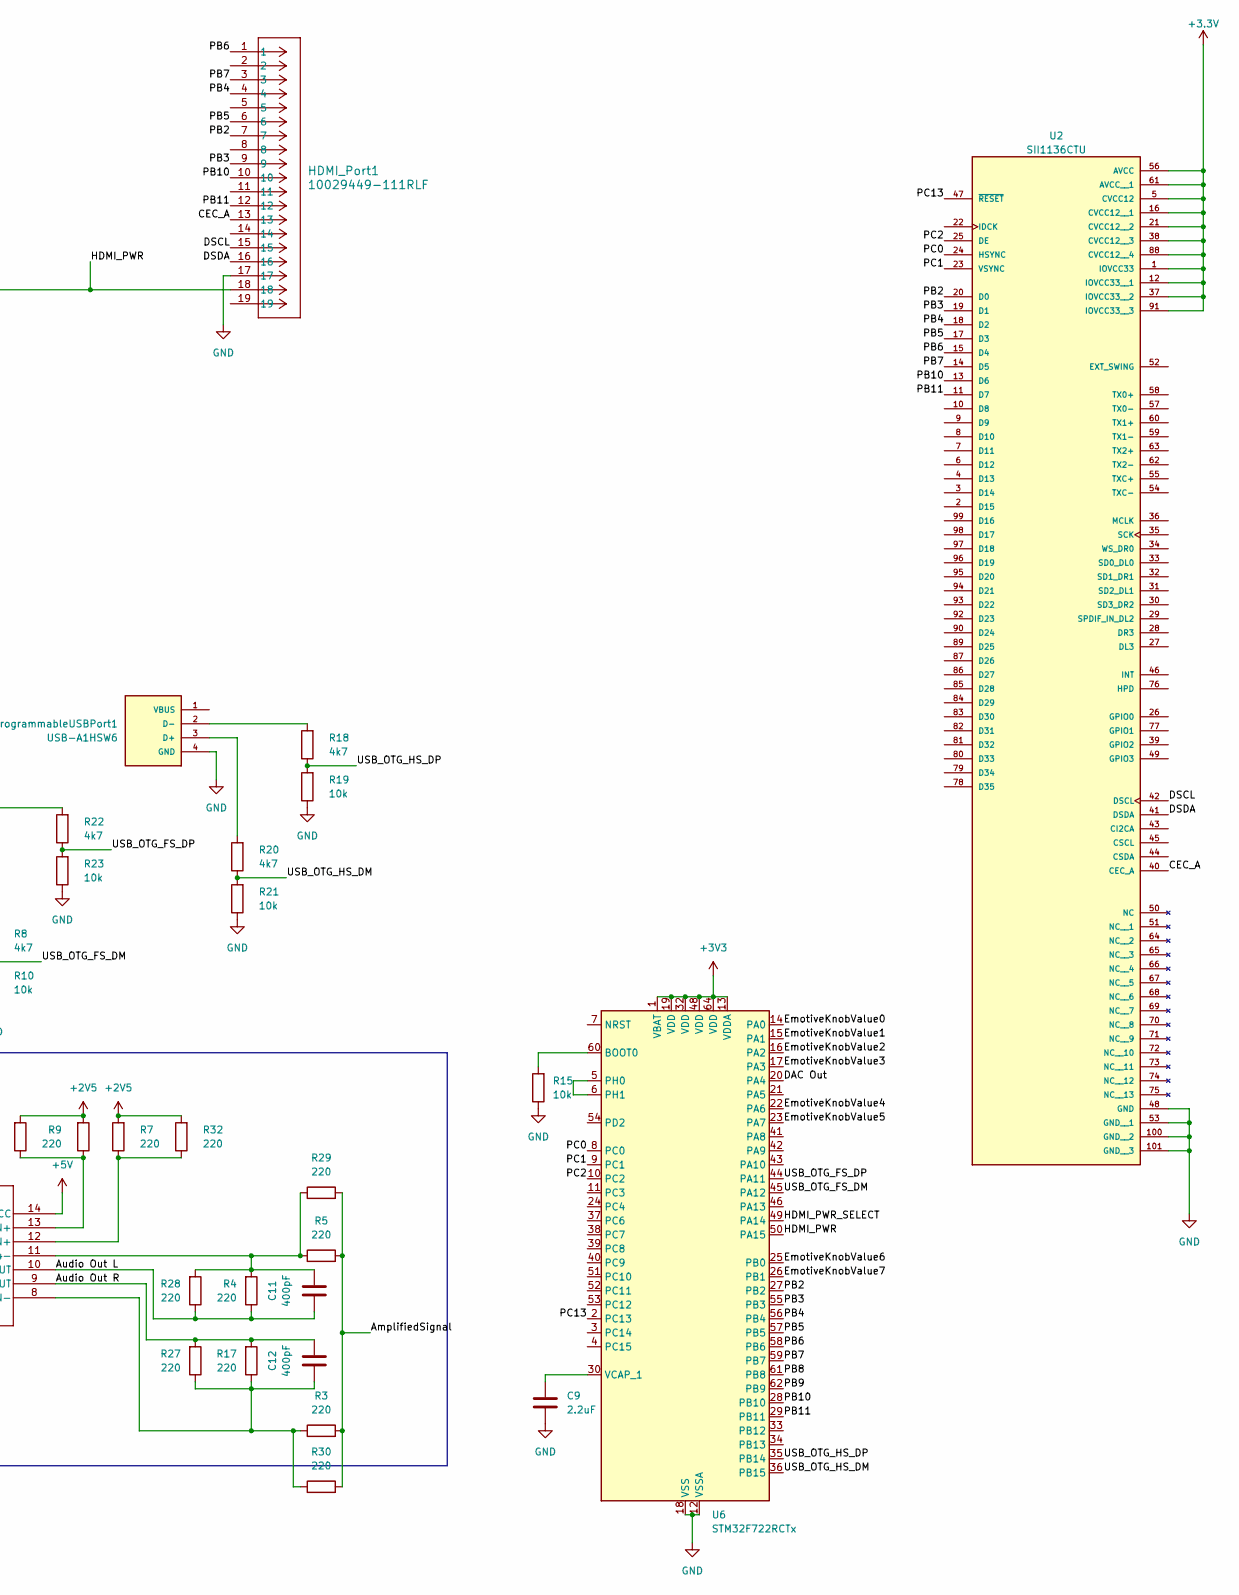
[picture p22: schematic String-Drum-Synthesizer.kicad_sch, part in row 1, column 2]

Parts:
AudioJack1: Conn_01x03_Pin; Molex_KK-254_AE-6410-03A_1x03_P2.54mm_Vertical
C1, C3, C5: 0.1uF; C_Disc_D6.0mm_W4.4mm_P5.00mm
C2, C4, C6, C7: 10uF; CP_Radial_D7.5mm_P2.50mm
C8: 0.01u; C_Disc_D6.0mm_W4.4mm_P5.00mm
C9: 2.2uF; C_Disc_D6.0mm_W4.4mm_P5.00mm
C11, C12: 400pF; C_Disc_D6.0mm_W4.4mm_P5.00mm
HDMI_Port1: 10029449-111RLF; CONN_10029449111_AMP
KeyboardUSBPort1: USB-A1HSW6; OST_USB-A1HSW6; PARTREV A
Pot0, Pot1, Pot2, Pot3, Pot4, Pot5, Pot6, Pot7: EmotiveKnob; Molex_KK-254_AE-6410-03A_1x03_P2.54mm_Vertical
Pot8: Volume (100k); Molex_KK-254_AE-6410-03A_1x03_P2.54mm_Vertical
ProgrammableUSBPort1: USB-A1HSW6; OST_USB-A1HSW6; PARTREV A
R1, R12: 2k; R_Axial_DIN0207_L6.3mm_D2.5mm_P7.62mm_Horizontal
R2: 3.3k; R_Axial_DIN0207_L6.3mm_D2.5mm_P7.62mm_Horizontal
R3, R4, R5, R7, R9, R17, R27, R28, R29, R30, R31, R32: 220; R_Axial_DIN0207_L6.3mm_D2.5mm_P7.62mm_Horizontal
R6: 820; R_Axial_DIN0207_L6.3mm_D2.5mm_P7.62mm_Horizontal
R8, R18, R20, R22: 4k7; R_Axial_DIN0207_L6.3mm_D2.5mm_P7.62mm_Horizontal
R10, R15, R19, R21, R23: 10k; R_Axial_DIN0207_L6.3mm_D2.5mm_P7.62mm_Horizontal
R11: 1k; R_Axial_DIN0207_L6.3mm_D2.5mm_P7.62mm_Horizontal
R13: 750; R_Axial_DIN0207_L6.3mm_D2.5mm_P7.62mm_Horizontal
R14, R16: 75k; R_Axial_DIN0207_L6.3mm_D2.5mm_P7.62mm_Horizontal
R24, R25, R26: 1M; R_Axial_DIN0207_L6.3mm_D2.5mm_P7.62mm_Horizontal
U1, U5: LM1117MP-3.3; SOT-223-3_TabPin2
U2: SII1136CTU; TQFP-100-1EP_14x14mm_P0.5mm_EP5x5mm
U3: 74LS257; DIP-16_W7.62mm_Socket
U4: LM3900DR; DIP-14_W7.62mm_Socket
U6: STM32F722RCTx; LQFP-64_10x10mm_P0.5mm

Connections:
+2V5: AudioJack1.3, C6.1, C8.1, R6.2, R7.2, R9.2, R11.1, R16.2, R31.2, R32.2, U5.2 (VO)
+3.3V: U2.1 (IOVCC33), U2.5 (CVCC12), U2.12 (IOVCC33__1), U2.16 (CVCC12__1), U2.21 (CVCC12__2), U2.37 (IOVCC33__2), U2.38 (CVCC12__3), U2.56 (AVCC), U2.61 (AVCC__1), U2.88 (CVCC12__4), U2.91 (IOVCC33__3)
+3V3: C4.1, Pot0.1, Pot1.1, Pot2.1, Pot3.1, Pot4.1, Pot5.1, Pot6.1, Pot7.1, R1.1, U1.2 (VO), U6.1 (VBAT), U6.13 (VDDA), U6.19 (VDD), U6.32 (VDD), U6.48 (VDD), U6.64 (VDD)
+5V: C1.1, C2.1, KeyboardUSBPort1.1 (VBUS), U1.3 (VI), U3.2 (I0a), U3.16 (VCC), U4.14 (VCC), U5.3 (VI); also elsewhere on the board
/AmplifiedSignal: Pot8.1, R3.2, R5.2, R29.2, R30.2, U4.5 (1OUT); also elsewhere on the board
/Audio Out L: AudioJack1.1, C11.1, R4.1, R28.1, U4.10 (4OUT)
/Audio Out R: AudioJack1.2, C12.2, R17.2, R27.2, U4.9 (3OUT)
/CEC_A: HDMI_Port1.13, U2.40 (CEC_A)
/DAC Out: C7.1, U6.20 (PA4)
/DSCL: HDMI_Port1.15, U2.42 (DSCL)
/DSDA: HDMI_Port1.16, U2.41 (DSDA)
/EmotiveKnobValue0: Pot0.2, U6.14 (PA0)
/EmotiveKnobValue1: Pot1.2, U6.15 (PA1)
/EmotiveKnobValue2: Pot2.2, U6.16 (PA2)
/EmotiveKnobValue3: Pot3.2, U6.17 (PA3)
/EmotiveKnobValue4: Pot4.2, U6.22 (PA6)
/EmotiveKnobValue5: Pot5.2, U6.23 (PA7)
/EmotiveKnobValue6: Pot6.2, U6.25 (PB0)
/EmotiveKnobValue7: Pot7.2, U6.26 (PB1)
/HDMI_PWR: HDMI_Port1.18, U3.4 (Za), U6.50 (PA15); also elsewhere on the board
/HDMI_PWR_SELECT: U3.1 (S), U6.49 (PA14); also elsewhere on the board
/PB2: HDMI_Port1.7, U2.20 (D0), U6.27 (PB2)
/PB3: HDMI_Port1.9, U2.19 (D1), U6.55 (PB3)
/PB4: HDMI_Port1.4, U2.18 (D2), U6.56 (PB4)
/PB5: HDMI_Port1.6, U2.17 (D3), U6.57 (PB5)
/PB6: HDMI_Port1.1, U2.15 (D4), U6.58 (PB6)
/PB7: HDMI_Port1.3, U2.14 (D5), U6.59 (PB7)
/PB8: U6.61 (PB8)
/PB9: U6.62 (PB9)
/PB10: HDMI_Port1.10, U2.13 (D6), U6.28 (PB10)
/PB11: HDMI_Port1.12, U2.11 (D7), U6.29 (PB11)
/PC0: U2.24 (HSYNC), U6.8 (PC0)
/PC1: U2.23 (VSYNC), U6.9 (PC1)
/PC2: U2.25 (DE), U6.10 (PC2)
/PC13: U2.47 (~RESET), U6.2 (PC13)
/USB_OTG_FS_DM: R8.1, R10.2, U6.45 (PA12)
/USB_OTG_FS_DP: R22.1, R23.2, U6.44 (PA11)
/USB_OTG_HS_DM: R20.1, R21.2, U6.36 (PB15)
/USB_OTG_HS_DP: R18.1, R19.2, U6.35 (PB14)
GND: C1.2, C2.2, C3.2, C4.2, C5.2, C6.2, C9.2, HDMI_Port1.17, KeyboardUSBPort1.4 (GND), Pot0.3, Pot1.3, Pot2.3, Pot3.3, Pot4.3, Pot5.3, Pot6.3, Pot7.3, ProgrammableUSBPort1.4 (GND), R2.2, R10.1, R12.2, R15.1, R19.1, R21.1, R23.1, R24.1, R25.1, R26.1, U2.48 (GND), U2.53 (GND__1), U2.100 (GND__2), U2.101 (GND__3), U3.3 (I1a), U3.5 (I0b), U3.6 (I1b), U3.8 (GND), U3.10 (I1d), U3.11 (I0d), U3.13 (I1c), U3.14 (I0c), U3.15 (OE), U4.7 (GND), U6.12 (VSSA), U6.18 (VSS), U6.31 (VSS), U6.47 (VSS), U6.63 (VSS); also elsewhere on the board
unnamed: C7.2, R6.1, R13.1
unnamed: C8.2, R13.2, R14.1
unnamed: KeyboardUSBPort1.3 (D+), R8.2
unnamed: KeyboardUSBPort1.2 (D-), R22.2
unnamed 44: Pot8.2, Pot8.3, R14.2, U4.6 (1IN-); also elsewhere on the board
unnamed: ProgrammableUSBPort1.3 (D+), R20.2
unnamed: ProgrammableUSBPort1.2 (D-), R18.2
unnamed: C3.1, R1.2, R2.1, U1.1 (GND)
unnamed 48: R24.2, U3.7 (Zb); also elsewhere on the board
unnamed 49: R25.2, U3.12 (Zc); also elsewhere on the board
unnamed 50: R26.2, U3.9 (Zd); also elsewhere on the board
unnamed: R16.1, U4.1 (1IN+)
unnamed: R9.1, R31.1, U4.13 (3IN+)
unnamed: C12.1, R3.1, R17.1, R27.1, R30.1, U4.8 (3IN-)
unnamed: R7.1, R32.1, U4.12 (4IN+)
unnamed: C11.2, R4.2, R5.1, R28.2, R29.1, U4.11 (IN4-)
unnamed: C5.1, R11.2, R12.1, U5.1 (GND)
unnamed: R15.2, U6.60 (BOOT0)
unnamed: U6.5 (PH0), U6.6 (PH1)
unnamed: C9.1, U6.30 (VCAP_1)

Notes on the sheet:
Amplifier
Power Block
Emotive Knobs

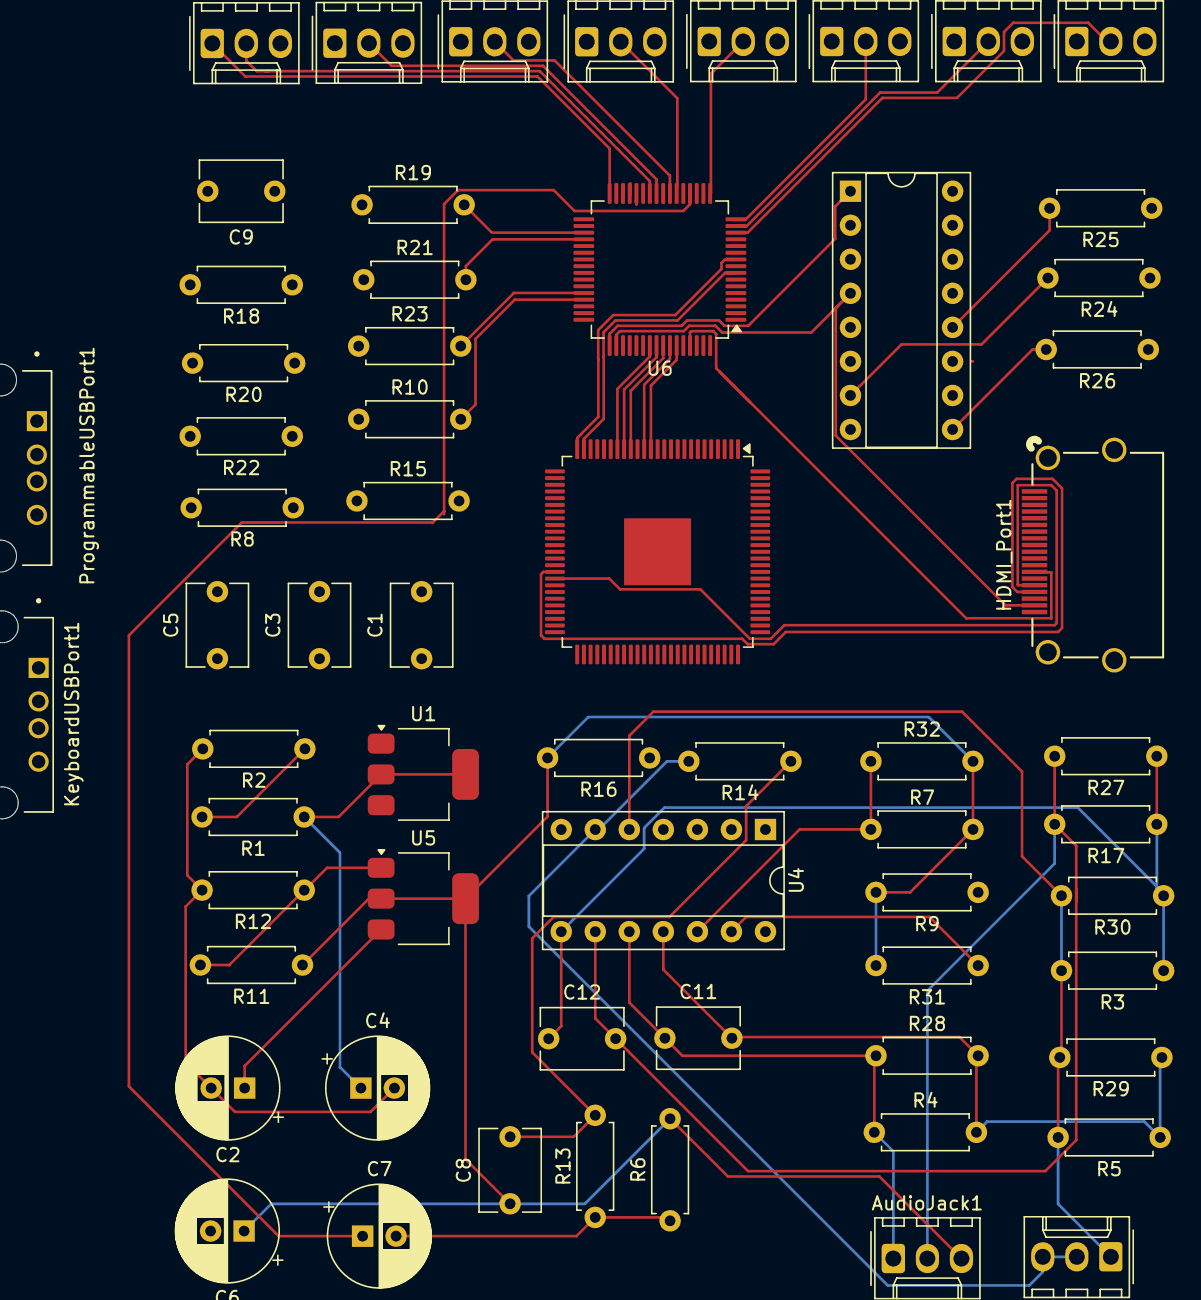
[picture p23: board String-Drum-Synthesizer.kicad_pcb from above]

Board: 2 copper layers, 62 parts (0 on the bottom side), 58 nets.

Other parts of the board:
74LS257: 74LS257; DIP-16_W7.62mm_Socket
Volume: Volume (100k); Molex_KK-254_AE-6410-03A_1x03_P2.54mm_Vertical

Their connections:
+5V: 74LS257.2 (I0a), 74LS257.16 (VCC); also elsewhere on the board
/AmplifiedSignal: Volume.1; also elsewhere on the board
/HDMI_PWR: 74LS257.4 (Za); also elsewhere on the board
/HDMI_PWR_SELECT: 74LS257.1 (S); also elsewhere on the board
GND: 74LS257.3 (I1a), 74LS257.5 (I0b), 74LS257.6 (I1b), 74LS257.8 (GND), 74LS257.10 (I1d), 74LS257.11 (I0d), 74LS257.13 (I1c), 74LS257.14 (I0c), 74LS257.15 (OE); also elsewhere on the board
unnamed 44: Volume.2, Volume.3; also elsewhere on the board
unnamed 48: 74LS257.7 (Zb); also elsewhere on the board
unnamed 49: 74LS257.12 (Zc); also elsewhere on the board
unnamed 50: 74LS257.9 (Zd); also elsewhere on the board

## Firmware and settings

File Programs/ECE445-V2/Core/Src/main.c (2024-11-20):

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
/* Includes ------------------------------------------------------------------*/
#include "main.h"

/* USER CODE BEGIN PD */
#define BUFFER_SIZE 256

/* USER CODE END PD */

ADC_HandleTypeDef hadc1;

I2S_HandleTypeDef hi2s2;
DMA_HandleTypeDef hdma_spi2_tx;

UART_HandleTypeDef huart2;

/* USER CODE BEGIN PV */
uint32_t last_adc_value = 0;
uint32_t current_adc_value = 0;
/* USER CODE END PV */

void SystemClock_Config(void);
static void MX_GPIO_Init(void);
static void MX_DMA_Init(void);
static void MX_USART2_UART_Init(void);
static void MX_ADC1_Init(void);
static void MX_I2S2_Init(void);
/* USER CODE BEGIN PFP */

int16_t audioBuffer[BUFFER_SIZE];
static volatile int16_t* audioBufferPtr = &audioBuffer[0];

uint8_t dataReadyFlag;

/* USER CODE END PFP */

/* USER CODE BEGIN 0 */
void HAL_I2SEx_TxRxHalfCpltCallBack(I2S_HandleTypeDef *hi2s)
{
	audioBufferPtr = &audioBuffer[0];
	dataReadyFlag = 1;
}

void HAL_I2SEx_TxRxCpltCallBack(I2S_HandleTypeDef *hi2s)
{
	audioBufferPtr = &audioBuffer[BUFFER_SIZE];
	dataReadyFlag = 1;
}

void GetNextBuffer()
{
	for (uint16_t i = 0; i < (BUFFER_SIZE / 2) - 1; i += 2)
	{
		const double sample = (double)((1 << 16) - 1) * ((double)(i) / (double)(BUFFER_SIZE));
		audioBufferPtr[i]   = (int16_t)(sample); // left
		audioBufferPtr[i+1] = (int16_t)(sample); // right
	}
	dataReadyFlag = 0;
}

void InitAudioBuffer()
{
	HAL_StatusTypeDef status = HAL_I2SEx_TransmitReceive_DMA(&hi2s2, (uint16_t*)audioBufferPtr, NULL, BUFFER_SIZE);
}

void Loop()
{
	if (dataReadyFlag)
	{
		GetNextBuffer();
	}
}
/**
  * @brief  Redirects printf output to UART.
  * @param  ch: The character to output.
  * @retval The character written to the UART.
  */
int __io_putchar(int ch)
{
  // Send the character via UART
  HAL_UART_Transmit(&huart2, (uint8_t*)&ch, 1, HAL_MAX_DELAY);
  return ch;
}

/* USER CODE END 0 */

/**
  * @brief  The application entry point.
  * @retval int
  */
int main(void)
{

  /* MCU Configuration--------------------------------------------------------*/

  /* Reset of all peripherals, Initializes the Flash interface and the Systick. */
  HAL_Init();

  /* Configure the system clock */
  SystemClock_Config();

  /* Initialize all configured peripherals */
  MX_GPIO_Init();
  MX_DMA_Init();
  MX_USART2_UART_Init();
  MX_ADC1_Init();
  MX_I2S2_Init();
  InitAudioBuffer();

  /* Infinite loop */
  /* USER CODE BEGIN WHILE */
  while (1)
  {
    /* USER CODE END WHILE */
	  Loop();
    /* USER CODE BEGIN 3 */
  }
  /* USER CODE END 3 */
}

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


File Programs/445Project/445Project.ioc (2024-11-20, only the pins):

Mcu.UserName=STM32F722RCTx
PA0-WKUP.Signal=ADCx_IN0
PA1.Signal=ADCx_IN1
PA11.Signal=USB_OTG_FS_DM
PA12.Signal=USB_OTG_FS_DP
PA13.Signal=SYS_JTMS-SWDIO
PA14.Signal=SYS_JTCK-SWCLK
PA2.Signal=ADCx_IN2
PA3.Signal=ADCx_IN3
PA4.Signal=COMP_DAC1_group
PA5.Signal=ADCx_IN5
PA6.Signal=ADCx_IN6
PA7.Signal=ADCx_IN7
PA9.Signal=USB_OTG_FS_VBUS
PB0.Signal=ADCx_IN8
PB1.Signal=GPIO_Output
PB10.Signal=GPIO_Output
PB11.Signal=GPIO_Output
PB12.Signal=GPIO_Output
PB13.Signal=GPIO_Output
PB14.Signal=USB_OTG_HS_DM
PB15.Signal=USB_OTG_HS_DP
PB2.Signal=GPIO_Output
PB3.Signal=GPIO_Output
PB4.Signal=GPIO_Output
PB5.Signal=GPIO_Output
PB6.Signal=GPIO_Output
PB7.Signal=GPIO_Output
PB8.Signal=GPIO_Output
PB9.Signal=GPIO_Output
PH0-OSC_IN.Signal=RCC_OSC_IN
PH1-OSC_OUT.Signal=RCC_OSC_OUT

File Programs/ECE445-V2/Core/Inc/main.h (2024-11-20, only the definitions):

#define B1_Pin GPIO_PIN_13
#define B1_GPIO_Port GPIOC
#define USART_TX_Pin GPIO_PIN_2
#define USART_TX_GPIO_Port GPIOA
#define USART_RX_Pin GPIO_PIN_3
#define USART_RX_GPIO_Port GPIOA
#define Audio_Out_Pin GPIO_PIN_5
#define Audio_Out_GPIO_Port GPIOA
#define TMS_Pin GPIO_PIN_13
#define TMS_GPIO_Port GPIOA
#define TCK_Pin GPIO_PIN_14
#define TCK_GPIO_Port GPIOA
#define SWO_Pin GPIO_PIN_3
#define SWO_GPIO_Port GPIOB

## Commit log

2024-09-25 Schematic created
    [String-Drum-Synthesizer.kicad_sch]
2024-09-25 Power block done
    [String-Drum-Synthesizer.kicad_sch]
2024-09-26 Emotive Knobs in progress
    [String-Drum-Synthesizer.kicad_sch]
2024-10-02 Emotive Knob subsytem added
    [String-Drum-Synthesizer.kicad_sch]
2024-10-02 Amplifier subsystem added
    [String-Drum-Synthesizer.kicad_sch]
2024-10-02 Still needs proc details
    [String-Drum-Synthesizer.kicad_sch]
2024-10-04 Most recent schematic
    [String-Drum-Synthesizer.kicad_sch]
2024-10-04 Updated Amplifier Resistor Values
    [String-Drum-Synthesizer.kicad_sch]
2024-10-08 Final Schematic For Demo
    [String-Drum-Synthesizer.kicad_sch]
2024-10-08 Deleted a USB Port
    [String-Drum-Synthesizer.kicad_sch]
2024-10-14 Port added to schematic, but needs connections
    [String-Drum-Synthesizer.kicad_sch]
2024-10-14 Switched out op-amp for actual LM3900
    [String-Drum-Synthesizer.kicad_sch]
2024-10-14 Adding peripheral USB hardware
    [String-Drum-Synthesizer.kicad_sch]
2024-10-14 Added HDMI Chip
    [String-Drum-Synthesizer.kicad_sch]
2024-10-14 Added HDMIconfiguration
    [String-Drum-Synthesizer.kicad_sch]
2024-10-14 Current USB Port
    [String-Drum-Synthesizer.kicad_sch]
2024-10-14 Added gitignore
    [String-Drum-Synthesizer.kicad_sch]
2024-10-17 Schematic Done!!
    [String-Drum-Synthesizer.kicad_sch]
2024-10-17 Needs R and C Footprints
    [String-Drum-Synthesizer.kicad_sch]
2024-10-18 Fixed multiplexor pinout
    [String-Drum-Synthesizer.kicad_sch]
2024-10-22 Fixed HDMI Pinout. Have to start PCB design over
    [String-Drum-Synthesizer.kicad_pcb, String-Drum-Synthesizer.kicad_sch]
2024-10-23 Current Schem
    [String-Drum-Synthesizer.kicad_pcb]
2024-10-23 Current changes
2024-11-14 Updated code to accommodate single ADC configuration
2024-11-17 Implemented Sine Wave Test + Added Pin Config File
2024-12-16 Added schematic

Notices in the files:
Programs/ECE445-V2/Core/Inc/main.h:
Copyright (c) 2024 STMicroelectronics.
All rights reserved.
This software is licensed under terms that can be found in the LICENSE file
